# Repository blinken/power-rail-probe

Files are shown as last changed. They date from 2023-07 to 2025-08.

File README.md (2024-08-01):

# Power rail probe

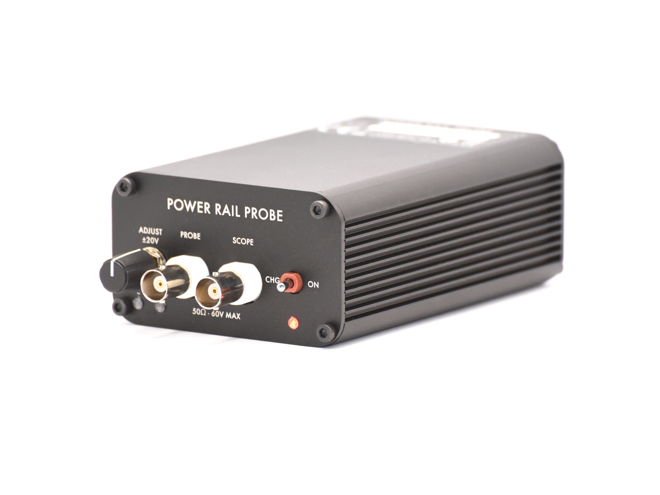
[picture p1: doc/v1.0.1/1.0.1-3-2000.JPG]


**An Open Hardware low-noise power rail oscilloscope probe**, loosely based on the excellent writeup by
[Andrew Levido](https://circuitcellar.com/research-design-hub/projects/building-a-power-rail-probe/)
[[PDF archive](doc/circuit_cellar-building_a_power_rail_probe.pdf)].

The probe allows you to measure millivolt-level ripple on a power rail up to 20V,
using a normal oscilloscope, by applying a vertical offset. This open design costs <10% of the price of the [Tektronix TPR1000](https://www.tek.com/en/datasheet/active-power-rail-probes).

Here's how it works:

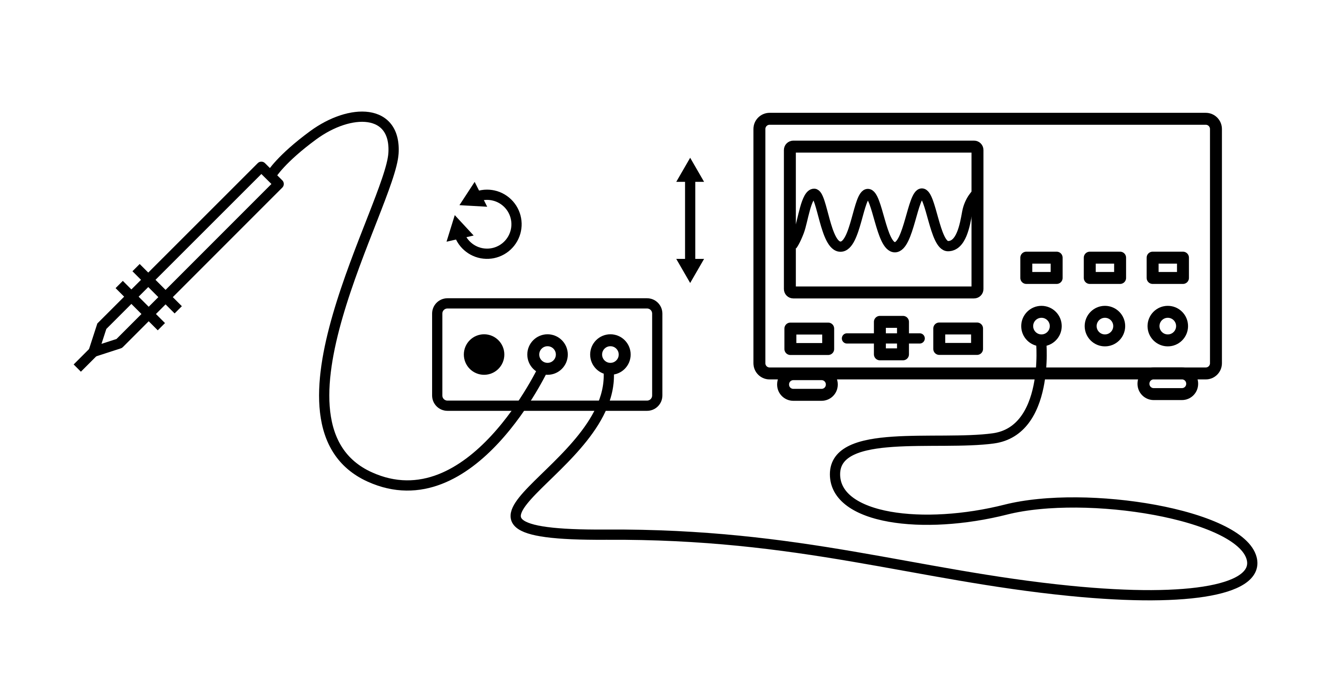
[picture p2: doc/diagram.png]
Connection diagram


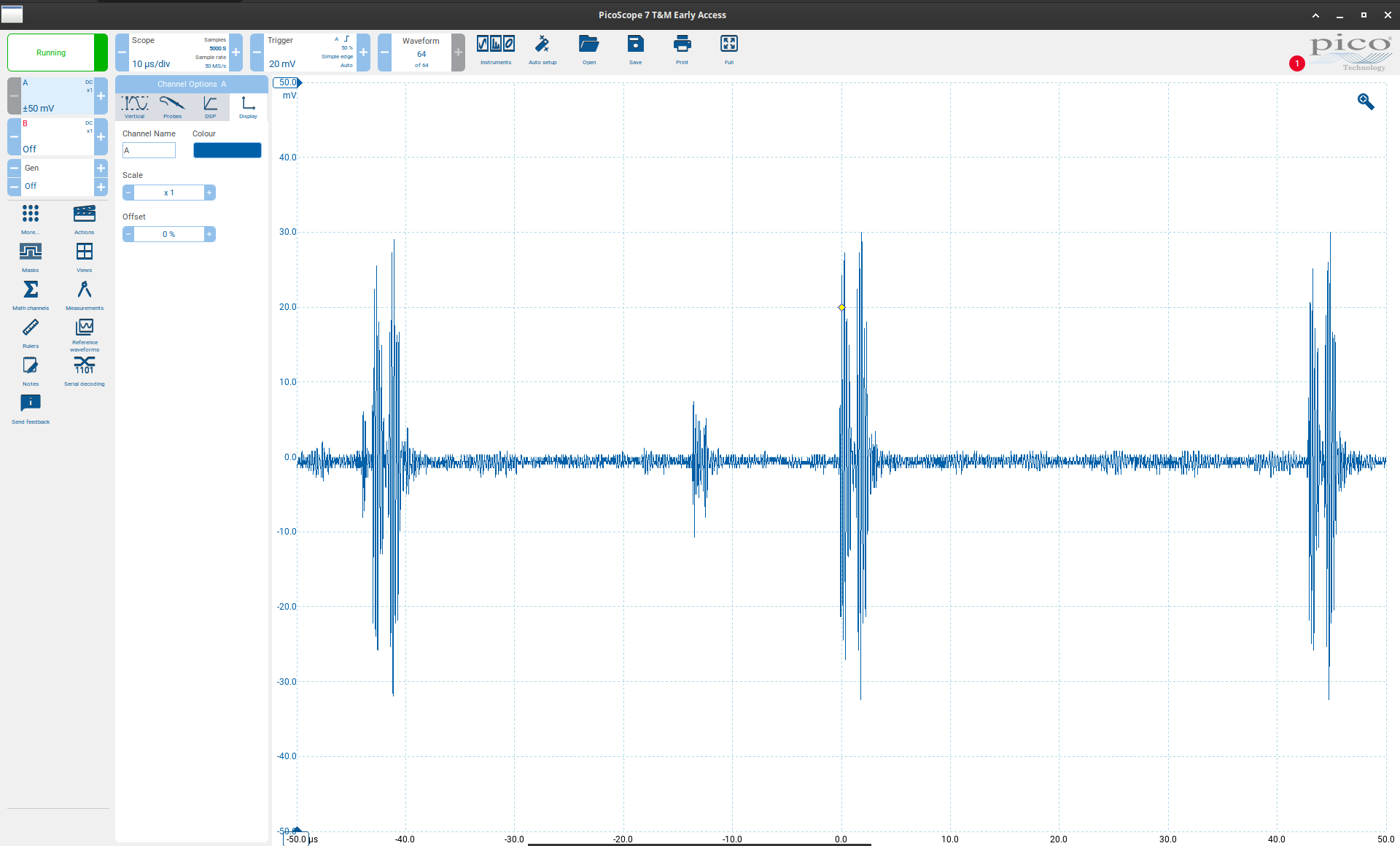
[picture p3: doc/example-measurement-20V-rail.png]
Example measurement showing ~50mV ripple on a 20V rail


*Measurement of 60mV p-p ripple on a 20V rail (ie. ripple 19.97V - 20.03V) using an inexpensive [Picoscope 2204A](https://www.picotech.com/oscilloscope/2000/picoscope-2000-specifications)*

The probe is directly connected to a power rail you're interested in (eg, via a
1X oscilloscope probe, or a direct cable connection).  AC is passed, and an
adjustable offset is applied to the DC voltage. The offset is fixed, allowing
DC sag and drift to be examined.

Your oscilloscope sees 0V DC, allowing power supply ripple and transients to be
viewed at the 1 mV/div setting, rather than 5 V/div. It's effectively a much
more powerful DC offset function for your oscilloscope.

## Specifications

### v1.0.1

 * Max voltage offset ±20V
 * Input impedance 50kΩ (0 - 30kHz) / 50Ω (30kHz - 1GHz)
 * Average signal attenuation of 1:1.2 (-0.9 dB +/- 1dB)
 * Frequency response (S12) flat within 1dB through 490MHz
 * Noise <500 µV<sub>p-p</sub> over full bandwidth
 * Active signal range ±1V
 * Indication of over-range signal (above or below offset setting)
 * High-precision Nidec M-1305 5-turn potentiometer for accurate offset adjustment
 * Isolation between chassis/USB and BNC test connectors
 * Battery powered to minimise noise
 * Li-Ion 18650 batteries rechargeable via USB-C connector (9V+ USB-PD supply required) or via DC barrel jack

The probe should be connected to an oscilloscope set to 50-ohm input impedance, and
works best with inputs <1-ohm impedance.

[Feedback and comments on the design](https://github.com/blinken/power-rail-probe/issues) are very much appreciated.

## How to buy

Version 1.0 is available [to purchase fully assembled here](https://paradar.co.uk/products/low-noise-oscilloscope-power-rail-probe)
for approx. £249 (USD $317, EUR €287). Purchasing a fully assembled unit helps to fund development!

If you would like to assemble the v1.0 probe yourself, blank PCBs, enclosures
and machined front panels are also available at [paradar.co.uk](https://paradar.co.uk/products/low-noise-oscilloscope-power-rail-probe).

Gerber files and a full BOM & schematic are available below under a CC BY-SA 4.0 license.

## Versions

The project is under active development, and there are several versions:

| Version | Status | Description | Performance |
| --- | --- | --- | --- |
| [v1.0](https://github.com/blinken/power-rail-probe/tree/v1.0) | Completed | Initial proof-of-concept | Functions well. Frequency response flat within 1.3dB to 500MHz. Similar (or slightly better) noise levels vs v1.1 |
| v1.0.1 | Complete, characterised and [available](https://paradar.co.uk/products/low-noise-oscilloscope-power-rail-probe) | Fix bugs from 1.0 and improve manufacturability | Improved frequency response vs v1.0, plus indicators for over/under range |
| v1.1 | Simulation complete | Includes additional compensation & lessons learned from v1.0 | Untested. Frequency response estimated from simulation as flat to within 0.5dB to 1GHz |

## Schematic

### v1.0

[[PDF](doc/schematic.pdf)] [[KiCanvas](https://kicanvas.org/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)]

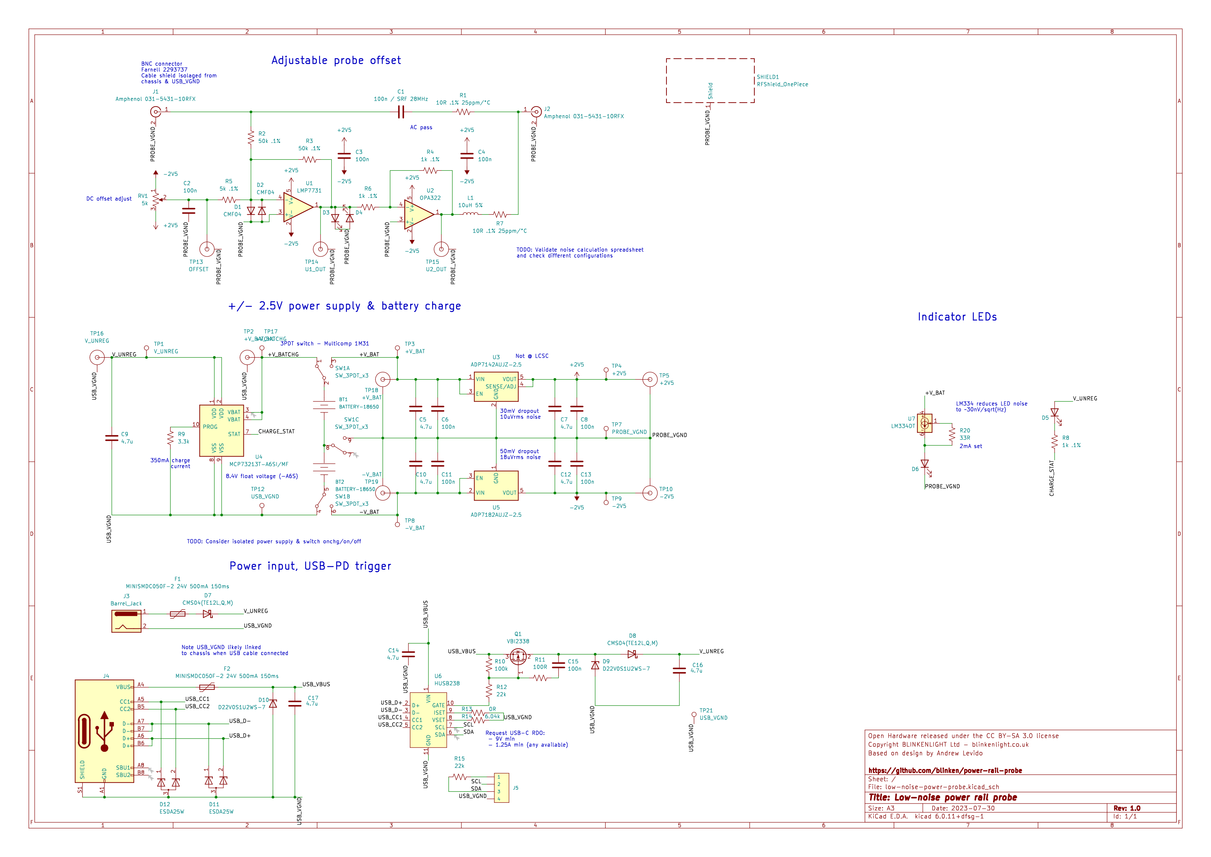
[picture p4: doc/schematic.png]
Power rail probe, schematic


### v1.0.1

[[KiCanvas](https://kicanvas.org/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)]

## Layout

### v1.0

[[PDF](doc/layout.pdf)] [[KiCanvas](https://kicanvas.org/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)]

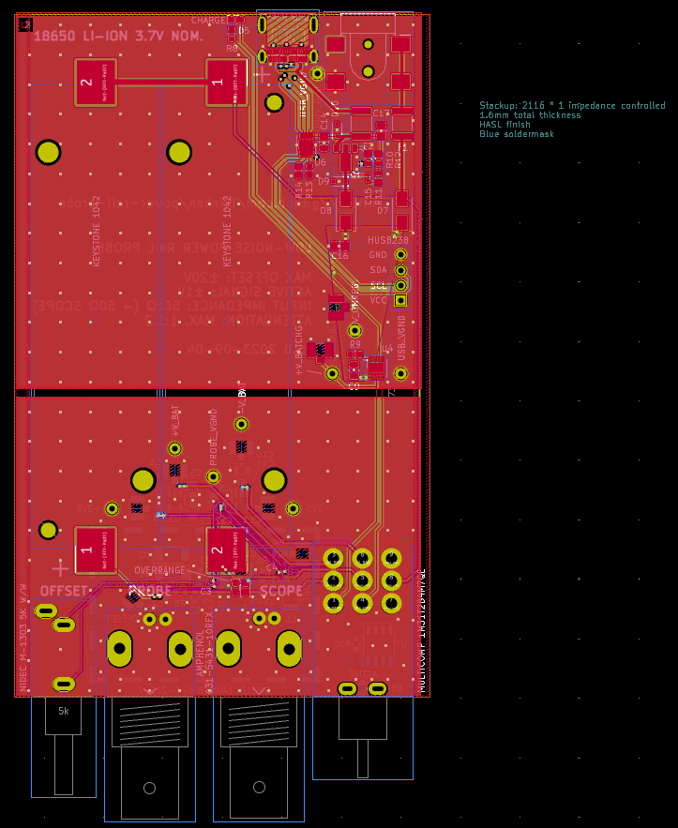
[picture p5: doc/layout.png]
Power rail probe, PCB layout


### v1.0.1

This version is under active development.

[[KiCanvas](https://kicanvas.org/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)]

## Frequency response

### v1.0.1

The probe's frequency response is flat within 1dB between approximately 3MHz and 490MHz, and flat within 2.5dB between approximately 150kHz and 550Mhz.

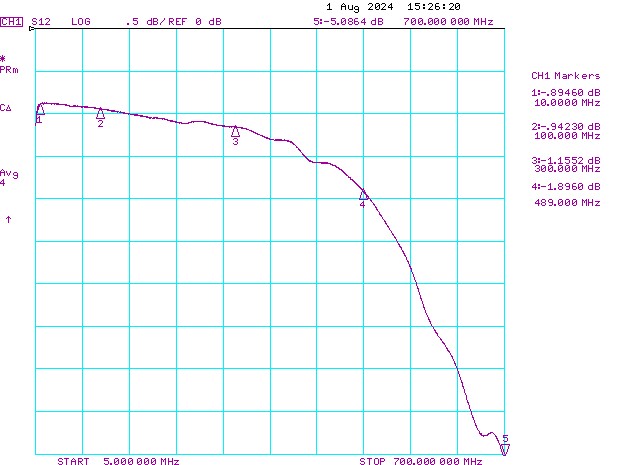
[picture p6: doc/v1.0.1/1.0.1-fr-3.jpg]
Chart of frequency response from 5MHz to 700MHz


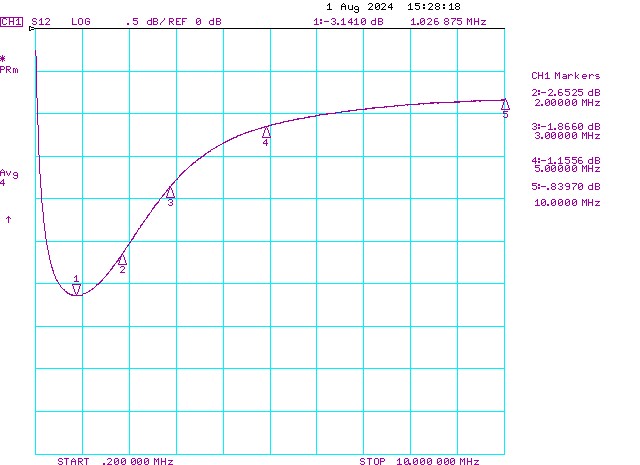
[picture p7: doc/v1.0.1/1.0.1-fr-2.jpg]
Chart of frequency response from 200kHz to 10MHz


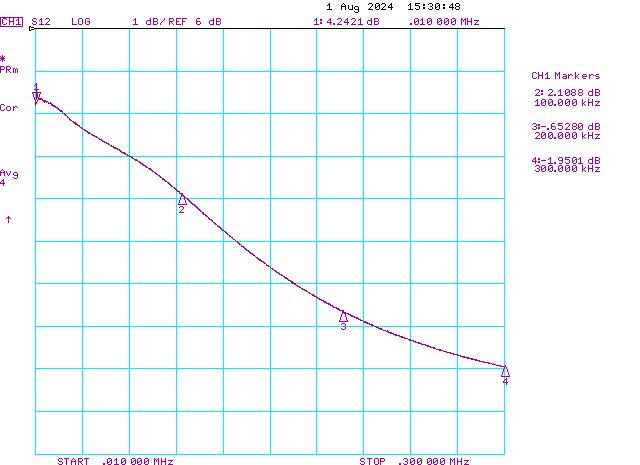
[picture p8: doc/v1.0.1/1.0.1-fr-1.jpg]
Chart of frequency response from 10kHz to 300kHz


### v1.0

Performance is flat within 1.3dB to 500MHz, aside from a 3.7dB dip at approx 1.2MHz.

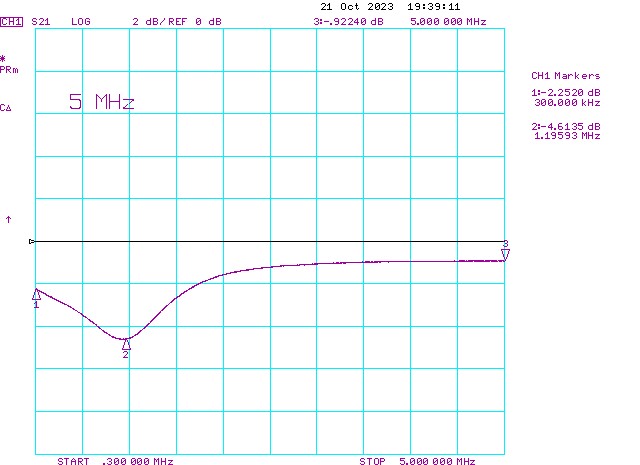
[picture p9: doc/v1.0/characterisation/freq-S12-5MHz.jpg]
Chart of frequency response from 300kHz to 5MHz


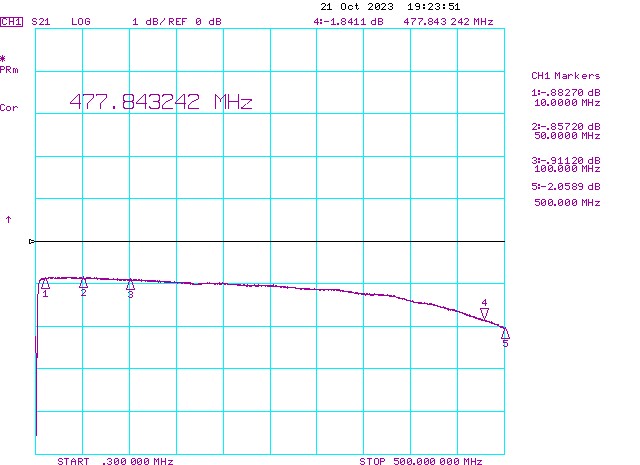
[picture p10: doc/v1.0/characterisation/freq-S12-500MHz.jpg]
Chart of frequency response from 300kHz to 500MHz


### v1.1

This version has not yet been manufactured, and the results below are from simulation in SPICE.

Frequency response is flat within 0.5dB to 1GHz, with the exception of a 2.5dB peak at 71.8kHz.

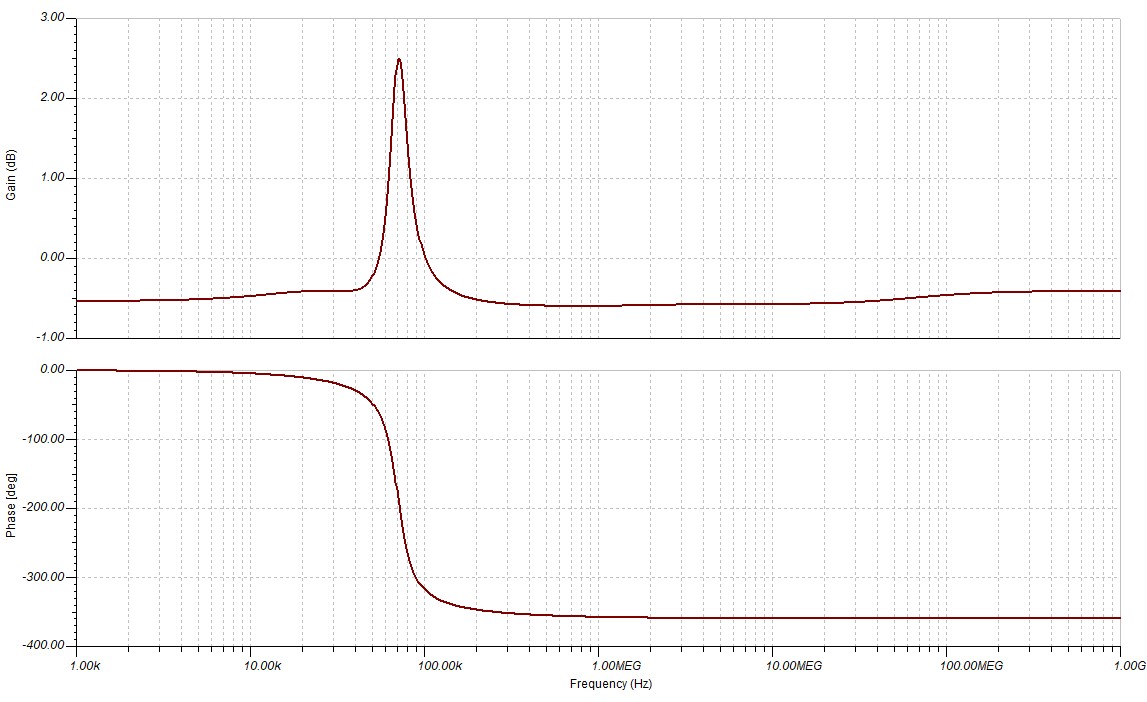
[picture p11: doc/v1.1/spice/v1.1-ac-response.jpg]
Chart frequency response 10Hz and 1GHz


The chart above was obtained through simulation with TINA-TI SPICE, assuming an
input impedance of 0.1Ω. Measuring the frequency response with a 50Ω source
(ie. a standard VNA) will produce different results.

[[Simulation files](./doc/v1.1/spice)]

## Noise analysis

The design aims to minimise the noise introduced by the instrument. Low-noise
operation is achieved with battery operation, and by avoiding semiconductors in
the critical path.  Batteries are recharged when the instrument is turned off.

### v1.0 & v1.1

The total noise introduced by the probe ([simulated in TINA-TI SPICE v9](./doc/v1.1/spice)) is
78.7 µVrms when measuring over the total instrument bandwidth 10Hz and 1GHz.

The noise introduced depends on the bandwidth of the measurement. Reducing the
measured bandwidth will reduce the noise introduced, and so the numbers below
are a worst-case upper limit. For example, a measurement between 10kHz and
20kHz, the probe will introduce 12.9 µVrms noise (-84.8 dBm).

| Measurement bandwidth  | Total RMS noise | Total peak-to-peak noise (6σ) | Power (Z<sub>0</sub>=50Ω) |
| --- | --- | --- | --- |
| 10Hz - 10kHz | 12.9 µV<sub>rms</sub> | 77.4 µV<sub>p-p</sub> | -84.8 dBm |
| 1kHz - 10kHz | 11.9 µV<sub>rms</sub> | 71.4 µV<sub>p-p</sub> | -85.5 dBm |
| 10Hz - 100kHz | 76.3 µV<sub>rms</sub> | 457.8 µV<sub>p-p</sub> | -69.3 dBm |
| 10Hz - 1MHz | 78.4 µV<sub>rms</sub> | 470.4 µV<sub>p-p</sub> | -69.1 dBm |
| 10Hz - 10MHz | 78.5 µV<sub>rms</sub> | 471.0 µV<sub>p-p</sub> | -69.1 dBm |
| 10Hz - 100MHz | 78.5 µV<sub>rms</sub> | 471.0 µV<sub>p-p</sub> | -69.1 dBm |
| 10Hz - 1GHz | 78.7 µV<sub>rms</sub> | 472.2 µV<sub>p-p</sub> | -69.1 dBm |

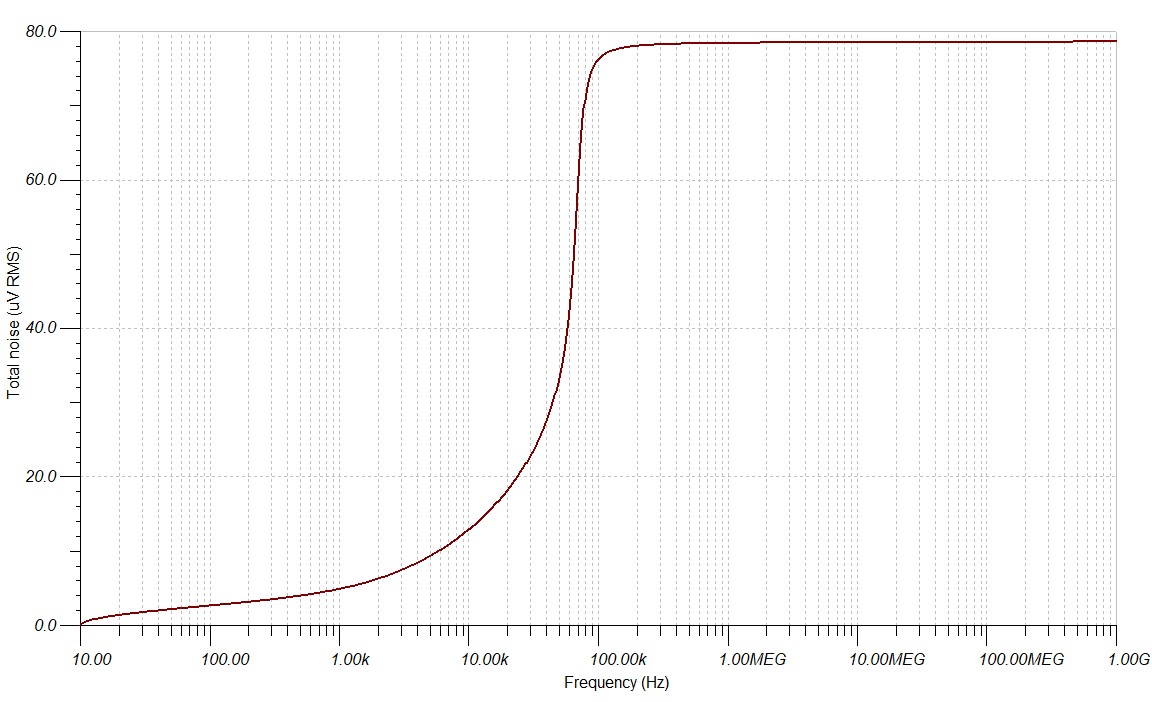
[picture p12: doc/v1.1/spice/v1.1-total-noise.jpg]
Chart of total noise between 10Hz and 1GHz


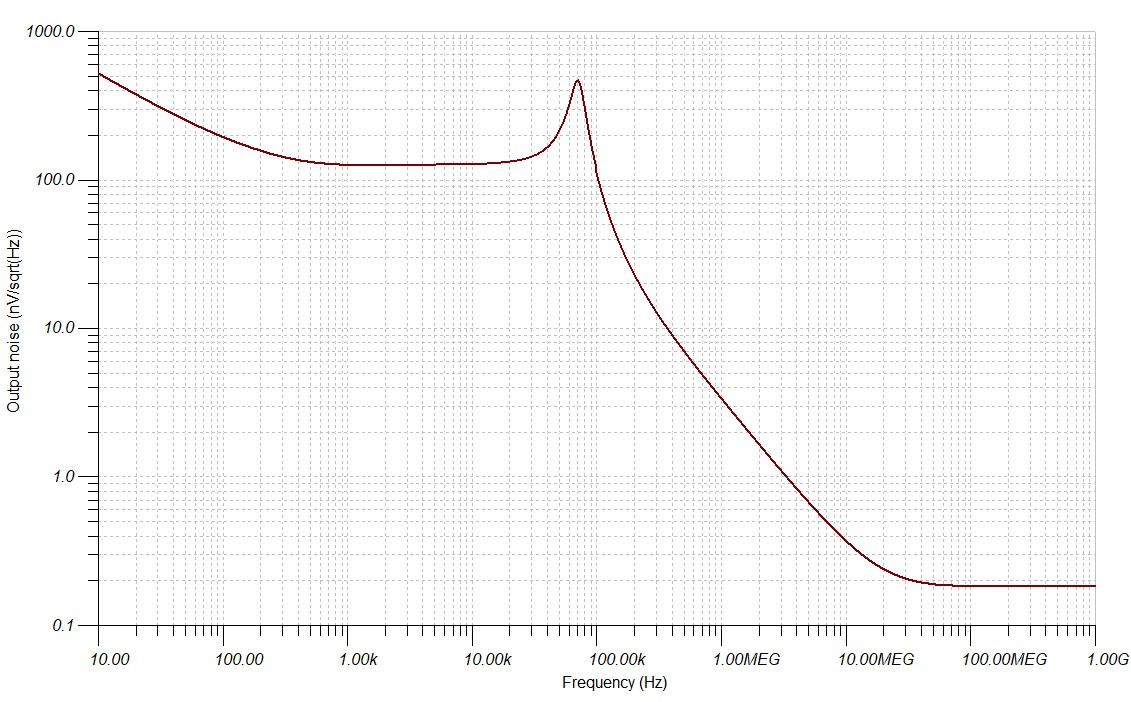
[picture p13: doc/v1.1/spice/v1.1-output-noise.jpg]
Chart of output noise between 10Hz and 1GHz


## Bill of materials

### v1.0

[[CSV](./bom/low-noise-power-probe-bom-pcba.csv)]

 * [LMP7731](https://www.ti.com/lit/ds/symlink/lmp7731.pdf) Ultra-low noise precision RRIO opamp
 * [OPA322](https://www.ti.com/lit/ds/symlink/opa322.pdf) 20-MHz low-noise 1.8-V RRIO opamp
 * [ADP7142AUJZ-2.5](https://www.analog.com/media/en/technical-documentation/data-sheets/ADP7142.pdf) +2.5V 200 mA low noise LDO Linear Regulator
 * [ADP7182AUJZ-2.5](https://www.analog.com/media/en/technical-documentation/data-sheets/ADP7182.pdf) -2.5V 200 mA low noise LDO Linear Regulator
 * [MCP73213T-A6SI/MF](https://ww1.microchip.com/downloads/aemDocuments/documents/OTH/ProductDocuments/DataSheets/20002190D.pdf) Dual-cell, Li-Ion/Li-Polymer charge management controller, 8.4V float
 * [HUSB238](https://en.hynetek.com/uploadfiles/site/219/news/1ad9e8fa-b39c-46a5-a984-152771d4ac69.pdf) Standalone USB PD sink controller
 * 2x [Amphenol 031-5431-10RFX](https://www.farnell.com/cad/2353820.pdf) isolated BNC connectors
 * [Multicomp 1M31T2B4M7QE](https://www.farnell.com/datasheets/1810474.pdf) 3PDT switch
 * [Molex 105450-0101](https://www.molex.com/en-us/products/part-detail/1054500101) USB-C receptacle
 * [Nidec M-1303](https://www.mouser.co.uk/datasheet/2/972/m-1827099.pdf) 5k 3-turn potentiometer
 * [DC050-T](https://datasheet.lcsc.com/lcsc/1912111437_SHOU-HAN-DC050-T_C431534.pdf) barrel jack connector
 * Selection of SMD resistors, capacitors, LEDs and diodes as marked
 * An aluminium extrusion case suitable for a 70x114mm board - eg, [AliExpress](https://www.aliexpress.com/item/1005003326971939.html)

A blank PCB, aluminium extrusion case and machined front/rear panels can be purchased as a kit from [paradar.co.uk](https://paradar.co.uk/products/low-noise-oscilloscope-power-rail-probe?variant=43212423233713).

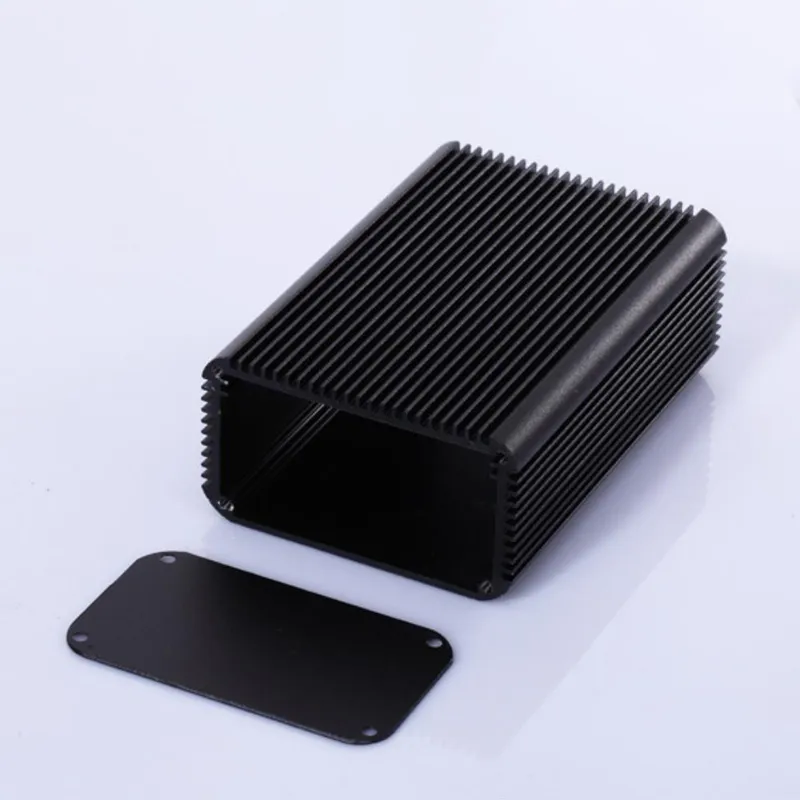
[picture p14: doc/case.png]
Aluminium enclosure 70x115mm internal size

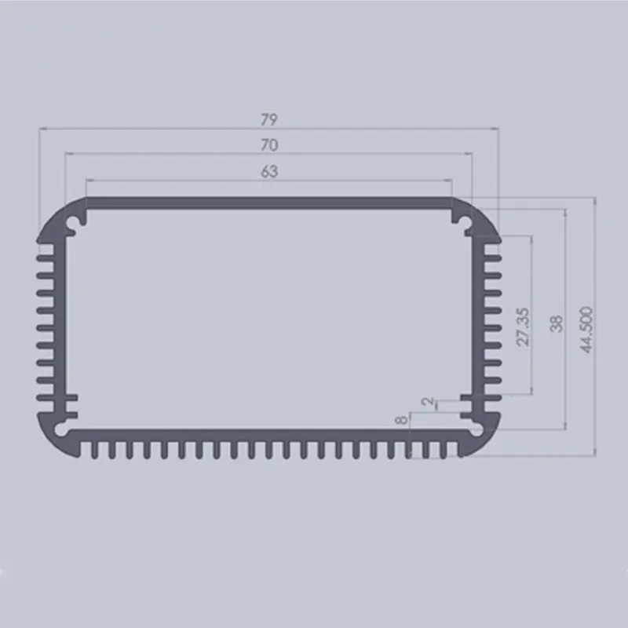
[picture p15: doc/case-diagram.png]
Aluminium enclosure, diagram with dimensions


## Front/rear panel layout

### v1.0

Click to expand.

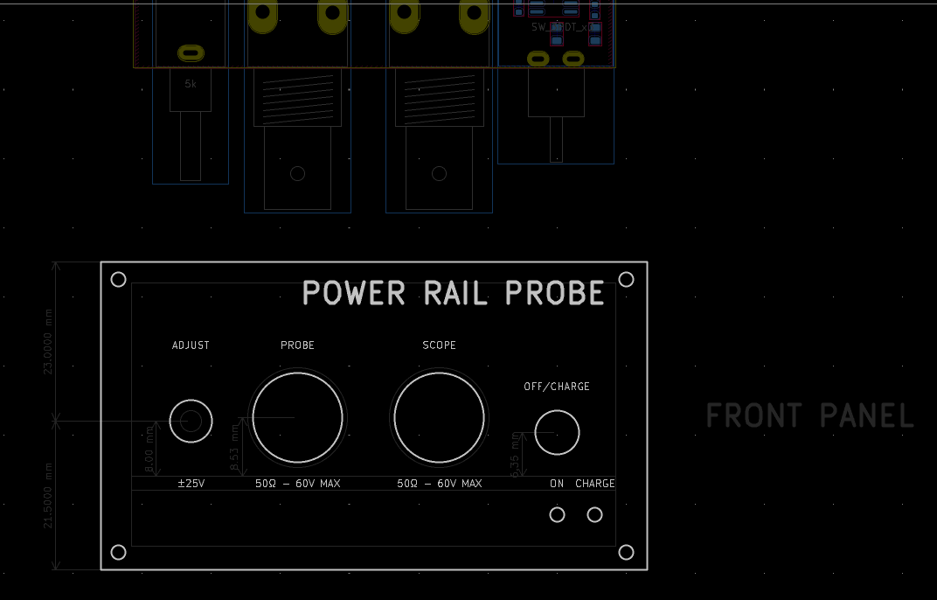
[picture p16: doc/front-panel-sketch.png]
Power rail probe, front panel layout diagram

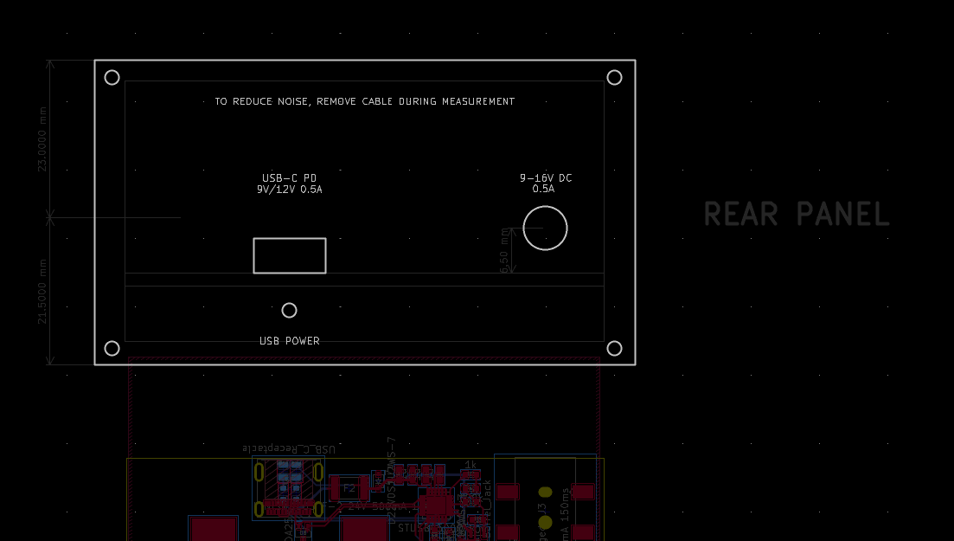
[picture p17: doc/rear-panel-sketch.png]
Power rail probe, rear panel layout diagram


## License

[CC BY-SA 4.0](https://creativecommons.org/licenses/by-sa/4.0/)

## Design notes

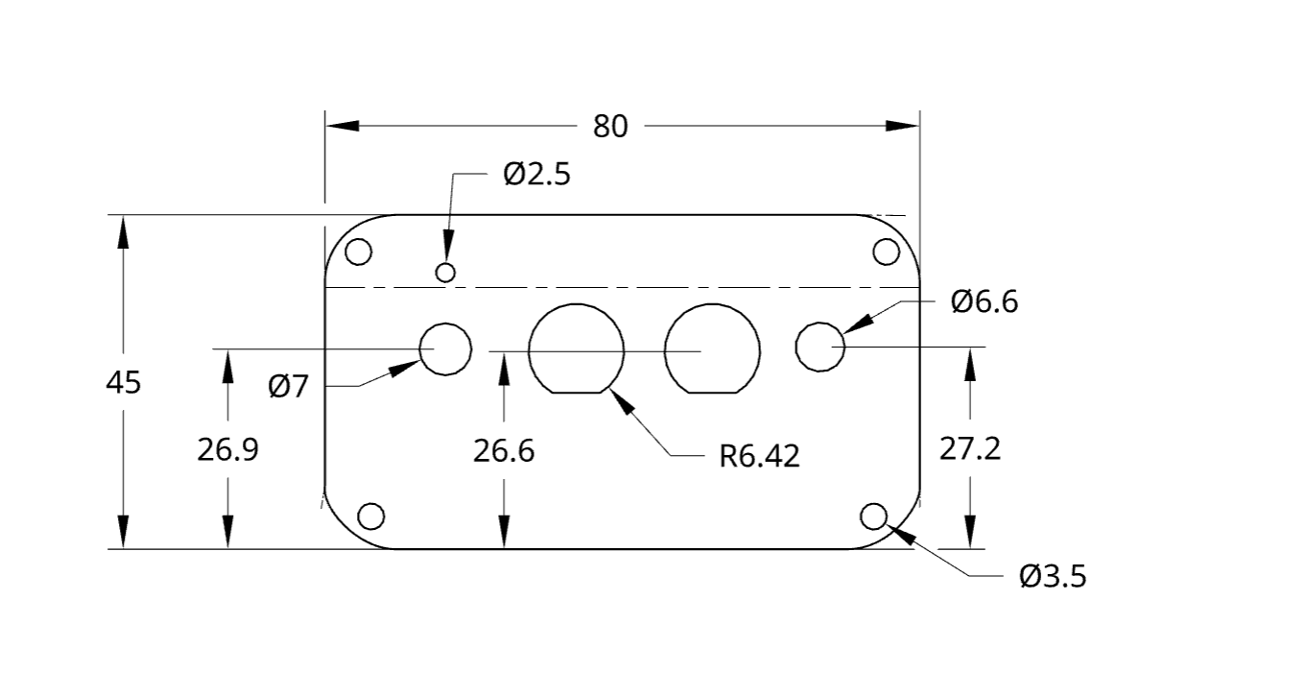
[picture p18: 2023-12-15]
doc/front-panel-drawing.png

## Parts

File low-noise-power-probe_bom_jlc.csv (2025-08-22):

Comment | Designator | Footprint | LCSC Part Number
Dual_Battery_Cell | BT1 | Battery-holder-18650-MYOUNG-BH-18650-A1BJ021 | C20606804
100n / SRF 28MHz | C1 | C_0402_1005Metric | C77020
100n | C2,C15,C16,C17,C18,C20,C23 | C_0402_1005Metric | C77020
2.2u | C4,C6,C8,C11,C13,C21,C22,C24,C25 | C_0402_1005Metric | C2999759
4.7u | C5,C7,C9,C10,C12,C14 | C_0805_2012Metric | C162420
Red 1.8V | D1,D3,D4,D5,D6 | LED_0603_1608Metric_polaritysilk | C965799
3V3 | D2 | D_SOD-123 | C19077392
1N5819WS | D7,D8 | D_SOD-323 | C191023
SD24-MS | D9,D10,D11,D12,D13,D14,D15 | D_SOD-323_silkpolarity | C2982180
SMD1206-050C-24V | F1,F2,F3,F4 | Fuse_1206_3216Metric | C2843983
Amphenol 901-10138 | J1,J2 | SMA_Amphenol_901-10138_Horizontal | C5541227
DC-005 2.0 | J3 | BarrelJack_Horizontal | C16214
USB_C_Receptacle | J4 | USB_C_Receptacle_Molex_105450-0101 | C134092
RF Shield Clip | J8,J9,J11,J12 | ICSRC6508-015SFR | C238200
10uH 5% | L1 | L_1812_4532Metric | C3223474
WSE3099 | Q1 | SOT-89-3 | C148359
HL2312 | Q2,Q3 | SOT-23 | C28646272
10R 1% 200ppm/°C | R1,R7 | R_0603_1608Metric | C2791798
50k .1% | R2,R3 | R_0603_1608Metric | C304067
1k .1% | R4,R6 | R_0603_1608Metric | C2989112
3.3k | R5 | R_0603_1608Metric | C22978
1k | R8,R21,R23,R31 | R_0603_1608Metric | C2989112
5k | R9 | R_0603_1608Metric | C2828621
50k | R10,R22,R24,R30 | R_0603_1608Metric | C304067
100R | R11,R29,R32,R33 | R_0603_1608Metric | C22775
6.04k | R12,R14 | R_0603_1608Metric | C25977
0R | R13,R26 | R_0603_1608Metric | C21189
10M | R15 | R_0603_1608Metric | C7250
620 | R16,R17 | R_0603_1608Metric | C203710
33R | R20 | R_0603_1608Metric | C966651
150R | R27 | R_0603_1608Metric | C22808
270R | R28 | R_0603_1608Metric | C22966
OPA322 | U1,U2 | SOT-23-5 | C2057629
ADP7142AUJZ-2.5 | U3 | TSOT-23-5 | C9900054564
MCP73213T-A6SI/MF | U4 | DFN-10-1EP_3x3mm_P0.5mm_EP1.55x2.48mm | C481367
ADP7182AUJZ-2.5 | U5 | TSOT-23-5 | C462196
HUSB238 | U6 | DFN-10-1EP_3x3mm_P0.5mm_EP1.65x2.38mm | C7471904
LM334DT | U7 | SO-8_3.9x4.9mm_P1.27mm | C140388
LM311DR | U8 | SOIC-8_3.9x4.9mm_P1.27mm | C12597
~ | U9 | VSON-8-1EP_3x3mm_P0.65mm_EP1.65x2.4mm | C2865505

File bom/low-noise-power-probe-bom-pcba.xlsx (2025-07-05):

Item | Qty | Reference(s) | Value | Footprint | Datasheet | LCSC | Manufacturer | Part | Substitution permitted?
4 | 9 | C1, C2, C3, C4, C6, C8, C11, C13, C15 | 100n | Capacitor_SMD:C_0402_1005Metric | ~ | C77020 | Murata | GRM155R71H104KE14D | No
5 | 8 | C5, C7, C9, C10, C12, C14, C16, C17 | 4.7u | Capacitor_SMD:C_0805_2012Metric | ~ | C162420 | Murata | GRM21BR61H475KE51L | No
6 | 2 | D1, D2 | CMF04 | Diode_SMD:D_SOD-128 | https://www.mouser.co.uk/datasheet/2/408/CMF04_datasheet_en_20180615-1150848.pdf | C150146 | TOSHIBA | CMF04(TE12L,Q,M) | No
7 | 4 | D3, D4, D5, D6 | Red 1.8V | LED_SMD:LED_0603_1608Metric | https://datasheet.lcsc.com/lcsc/1810181516_Vishay-Intertech-TLMS1000-GS08_C241893.pdf | C241893 | Vishay Intertech | TLMS1000-GS08 | Yes
8 | 2 | D7, D8 | CMS04(TE12L,Q,M) | Diode_SMD:D_SMA | https://datasheet.lcsc.com/lcsc/2008241604_TOSHIBA-CMS04-TE12L-Q-M_C603062.pdf | C603062 | TOSHIBA | CMS04(TE12L,Q,M) | No
9 | 2 | D9, D10 | D22V0S1U2WS-7 | Diode_SMD:D_SOD-323 | https://datasheet.lcsc.com/lcsc/2201101700_Diodes-Incorporated-D22V0S1U2WS-7_C1974624.pdf | C1974624 | Diodes Incorporated | D22V0S1U2WS-7 | Yes
10 | 2 | D11, D12 | ESDA25W | Package_TO_SOT_SMD:SOT-323_SC-70 | https://datasheet.lcsc.com/lcsc/2201201600_STMicroelectronics-ESDA25W_C2935152.pdf | C2935152 | STMicroelectronics | ESDA25W | Yes
11 | 2 | F1, F2 | MINISMDC050F-2 24V 500mA 150ms | Fuse:Fuse_1812_4532Metric | https://datasheet.lcsc.com/lcsc/2108070630_Littelfuse-MINISMDC050F-2_C2649901.pdf | C2649901 | Littelfuse | MINISMDC050F-2 | Yes
13 | 1 | J3 | Barrel_Jack | misc:BarrelJack_Shou_Han_DC050-T_SMT_Horizontal | https://datasheet.lcsc.com/lcsc/1912111437_SHOU-HAN-DC050-T_C431534.pdf | C431534 | Shou Han | DC050-T | Yes
14 | 1 | J4 | USB_C_Receptacle | Connector_USB:USB_C_Receptacle_Molex_105450-0101 | https://datasheet.lcsc.com/lcsc/1811131824_MOLEX-1054500101_C134092.pdf | C134092 | Molex | 1054500101 | Yes
15 | 1 | L1 | 10uH 5% | Inductor_SMD:L_1210_3225Metric | ~ | C2045047 | Murata | LQH32NH100J23L | No
16 | 1 | Q1 | VBI2338 | Package_TO_SOT_SMD:SOT-89-3 | https://datasheet.lcsc.com/lcsc/2308161358_VBsemi-Elec-VBI2338_C416321.pdf | C416321 | VBsemi Elec | VBI2338 | Yes
17 | 2 | R1, R7 | 10R .1% 25ppm/°C | Resistor_SMD:R_0402_1005Metric | ~ | C705629 | Yageo | RT0402BRD0710RL | Yes
18 | 2 | R2, R3 | 50k .1% | Resistor_SMD:R_0603_1608Metric | ~ | C861451 | Yageo | RT0603BRD0750KL | Yes
19 | 3 | R4, R6, R8 | 1k .1% | Resistor_SMD:R_0603_1608Metric | ~ | C110776 | Yageo | RT0603BRD071KL | Yes
20 | 1 | R5 | 5k .1% | Resistor_SMD:R_0603_1608Metric | ~ | C862232 | Yageo | RT0603BRE075KL | Yes
21 | 1 | R9 | 3.3k | Resistor_SMD:R_0603_1608Metric | ~ | C108078 | Yageo | RC0603FR-073K3L | Yes
22 | 1 | R10 | 100k | Resistor_SMD:R_0603_1608Metric | ~ | C14675 | Yageo | RC0603FR-07100KL | Yes
23 | 1 | R11 | 100R | Resistor_SMD:R_0603_1608Metric | ~ | C105588 | Yageo | RC0603FR-07100RL | Yes
24 | 2 | R12, R15 | 22k | Resistor_SMD:R_0603_1608Metric | ~ | C114065 | Yageo | RC0603FR-0722KL | Yes
25 | 1 | R13 | 0R | Resistor_SMD:R_0603_1608Metric | ~ | C192909 | Yageo | AF0603FR-070RL | Yes
26 | 1 | R14 | 6.04k | Resistor_SMD:R_0603_1608Metric | ~ | C141680 | Yageo | RC0603FR-076K04L | Yes
27 | 1 | R20 | 33R | Resistor_SMD:R_0603_1608Metric | ~ | C108661 | Yageo | RC0603FR-0733RL | Yes
31 | 1 | TP5 | +2V5 | rf-connectors:U.FL-Hirose |  | C88374 | Hirose | U.FL-R-SMT-1(80) | Yes
32 | 1 | TP10 | -2V5 | rf-connectors:U.FL-Hirose |  | C88374 | Hirose | U.FL-R-SMT-1(80) | Yes
33 | 1 | TP13 | OFFSET | rf-connectors:U.FL-Hirose |  | C88374 | Hirose | U.FL-R-SMT-1(80) | Yes
34 | 1 | TP14 | U1_OUT | rf-connectors:U.FL-Hirose |  | C88374 | Hirose | U.FL-R-SMT-1(80) | Yes
35 | 1 | TP15 | U2_OUT | rf-connectors:U.FL-Hirose |  | C88374 | Hirose | U.FL-R-SMT-1(80) | Yes
36 | 1 | TP16 | V_UNREG | rf-connectors:U.FL-Hirose |  | C88374 | Hirose | U.FL-R-SMT-1(80) | Yes
37 | 1 | TP17 | +V_BATCHG | rf-connectors:U.FL-Hirose |  | C88374 | Hirose | U.FL-R-SMT-1(80) | Yes
38 | 1 | TP18 | +V_BAT | rf-connectors:U.FL-Hirose |  | C88374 | Hirose | U.FL-R-SMT-1(80) | Yes
39 | 1 | TP19 | -V_BAT | rf-connectors:U.FL-Hirose |  | C88374 | Hirose | U.FL-R-SMT-1(80) | Yes
40 | 1 | U1 | LMP7731 | Package_TO_SOT_SMD:SOT-23-5 | https://www.ti.com/lit/ds/symlink/lmp7731.pdf | C202252 | Texas Instruments | LMP7731MF | No
41 | 1 | U2 | OPA322 | Package_TO_SOT_SMD:SOT-23-5 | https://www.ti.com/lit/ds/symlink/opa322.pdf | C2057408 | Texas Instruments | OPA322AIDBVT | No
42 | 1 | U3 | ADP7142AUJZ-2.5 | Package_TO_SOT_SMD:TSOT-23-5 | https://www.analog.com/media/en/technical-documentation/data-sheets/ADP7142.pdf |  | Texas Instruments | ADP7142AUJZ-2.5 | No
43 | 1 | U4 | MCP73213T-A6SI/MF | Package_DFN_QFN:DFN-10-1EP_3x3mm_P0.5mm_EP1.55x2.48mm | https://ww1.microchip.com/downloads/aemDocuments/documents/OTH/ProductDocuments/DataSheets/20002190D.pdf | C481367 | Microchip Tech | MCP73213T-A6SI/MF | No
44 | 1 | U5 | ADP7182AUJZ-2.5 | Package_TO_SOT_SMD:TSOT-23-5 | https://www.analog.com/media/en/technical-documentation/data-sheets/ADP7182.pdf | C462196 | Analog Devices | ADP7182AUJZ-2.5-R7 | No
45 | 1 | U6 | HUSB238 | Package_DFN_QFN:DFN-10-1EP_3x3mm_P0.5mm_EP1.65x2.38mm | https://en.hynetek.com/uploadfiles/site/219/news/1ad9e8fa-b39c-46a5-a984-152771d4ac69.pdf | C7471904 | Hynetek | HUSB238_002DD | No
46 | 1 | U7 | LM334DT | Package_SO:SO-8_3.9x4.9mm_P1.27mm | https://datasheet.lcsc.com/lcsc/2304140030_STMicroelectronics-LM334DT_C140388.pdf | C140388 | STMicroelectronics | LM334DT | No

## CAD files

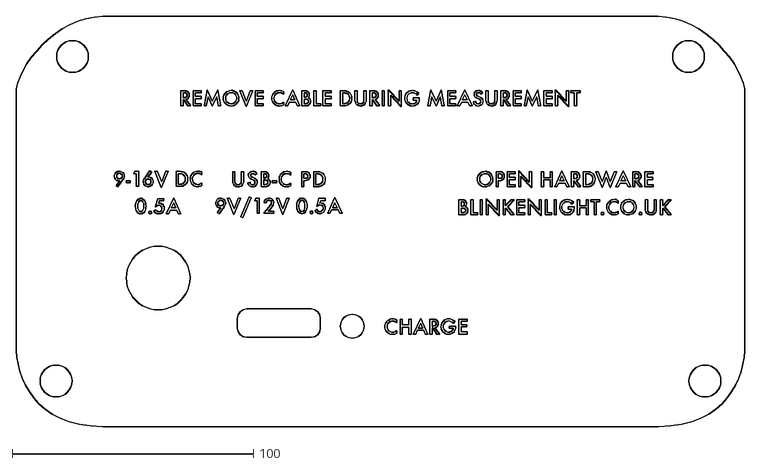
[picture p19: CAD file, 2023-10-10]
doc/rear-panel-marked-14.dxf
302.4 x 170.1

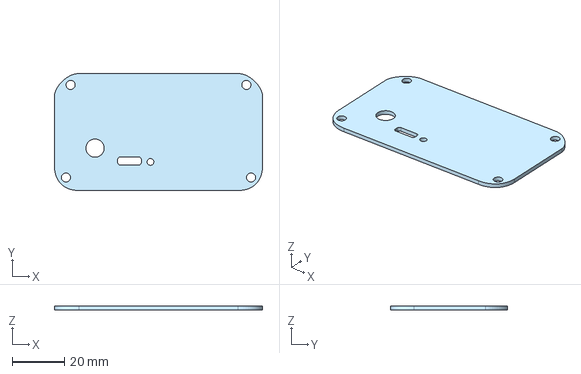
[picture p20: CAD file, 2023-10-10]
doc/rear-panel.step
80.0 x 45.0 x 1.50 mm

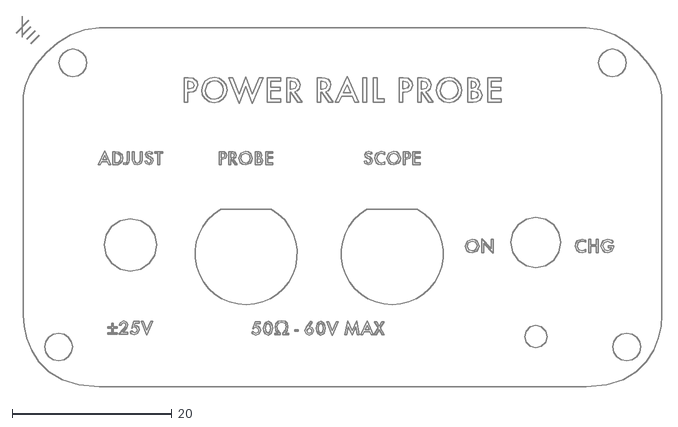
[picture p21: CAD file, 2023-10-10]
doc/front-panel-marked-14.dxf
80.9 x 46.5

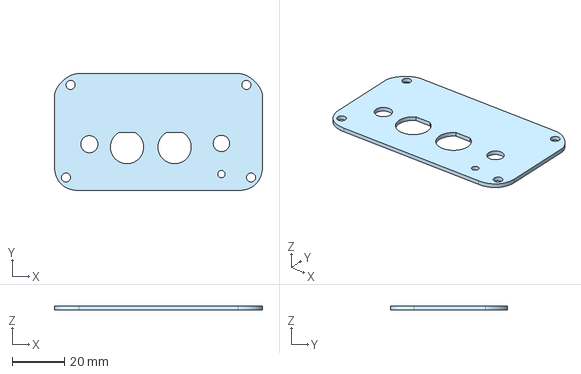
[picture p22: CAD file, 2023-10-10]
doc/front-panel.step
80.0 x 45.0 x 1.50 mm

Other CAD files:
doc/front-panel.3mf
doc/front-panel.dxf
doc/front-panel.stl
doc/rear-panel.3mf
doc/rear-panel.dxf
doc/rear-panel.stl

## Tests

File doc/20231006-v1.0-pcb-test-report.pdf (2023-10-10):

ITEM/项目 | DESCRIPTION/说明 | ACTUAL/结果
1 | Customer code/客户代码 | D0007
2 | Customer P/N/客户型号 | gb-low-noise-power-probe PCB
3 | Customer P/0/客户订单号 | PO20230907-1
4 | Shipment quantity/交货数量 | 10Pcs
5 | PCB type/PCB类型 | Rigid PCB
6 | Inspection standard/检查标准 | IPC-A-600H Class2
7 | UL plame class/UL number 耐燃与编 号 | 94V-0
8 | Laminate type/板材类型 | FR4 KB6167F TG≧170
9 | Surface Finish/表面处理 | HAL(LEAD-FREE)
10 | Date code /生产周期 | 3723
11 | Ship date / 出货日期 | 2023/9/19
12 | Production area/生产地 | China
13 | Meet with RoHS/符合RoHS | Yes
14 | Customer DWG/客户图纸 | Yes

Angel

Vic OuYang

Date : | 2023/9/19 | Signature

All PCBs are manufactured in comply with original Gerber and Specifications of customer requirement, After 100% inspection,the raw materials, fabrications,testing,appearance and functions of PCB are all conforming to customer SPEC and IPC standards,All data listed on this report hereby-certifition are truly to meet customer's request.

Thanks for your attention !!

Certified by : | Quality Assurance Manager

## CERTIFICATION OF COMPLIANCE

## Dear Customer:

尊敬的客户：

兹证明我们生产的印制电路板符合RoHS 欧盟指令 2011/65 及其修订指令2015/863 法规规定。

序号 NO. | 测试项目 Test Item | 限量 % Limit | 结果 Result
1 | 铅 Lead (pb) | 0.1(1000ppm) | Not detected
2 | 镉 Cadmium(Cd) | 0.01(100ppm) | Not detected
3 | 汞 Mercury(Hg). | 0.1(1000ppm) | Not detected
4 | 六价铬 Chromium VI(Cr+6 or CrVI) | 0.1(1000ppm) | Not detected
5 | 多溴联苯 PBBs | 0.1(1000ppm) | Not detected
6 | 多溴二苯醚 PBDEs | 0.1(1000ppm) | Not detected
7 | 邻苯二甲酸二异丁酯 DIBP | 0.1(1000ppm) | Not detected
8 | 邻苯二甲酸（2-乙基己基酯） DEHP | 0.1(1000ppm) | Not detected
9 | 邻苯二甲酸丁苄酯 BBP | 0.1(1000ppm) | Not detected
10 | 邻苯二甲酸二丁酯DBP | 0.1(1000ppm) | Not detected
Date/日期： | 2023/9/19 | Date/日期： | 2023/9/19
Prepared by/制作人： | Jenny | Approved by/审核人： | Lee

## RoHS Certificate of Compliance

### RoHS 符合性证明

Dear Customer,

This document declare that the above part number comply with the RoHS Directive 2002/95/EC, RoHS2 directive 2011/65/EU and RoHS3 directive 2015/863

Customer/客户代码： | D0007 | Customer Part No. 客户型号: | gb-low-noise-power-probe PCB

Item项目 | Description / 描述 | Specification / 规格 | Actual / 实际 | Acc/Rej
1.0 Visual Appearance/ 外观检查
2.0 Material 材料 | PCB Type /板类型 | Rigid PCB | Rigid PCB | ACC
| Material Type/ 基材类型 | FR4 KB6167F TG≧170 | FR4 KB6167F TG≧170 | ACC
| Finished Board Thk(mm)/完成板厚 | 1.6(+0.16/-0.16) | 1.58 | ACC
| Flammability Class : 防火等级 | 94V-0 | 94V-0 | ACC
3.0 Plating Thickness 镀层厚度 | Hole Wall Cu THK (Min) / 最小孔壁铜厚 | 20um | 25.3um | ACC
| Surface Cu THK / 完成铜厚 | 1OZ | 44.4um | ACC
| Plated Nickel (Min)/ 镀镍 | / | / | /
| Plated gold (Min)/ 镀金 | / | / | /
| Plated Tin/Lead /镀锡 | / | / | /
4.0 Line Inspection 导线检查 | Line Width (mm) / 线宽 | 0.183(+/-20%) | 0.190 | ACC
| Line Spacing (mm) / 线距 | 0.145(+/-20%) | 0.160 | ACC
5.0 Solder Mask 阻 焊 / Legend 字符 /Peelable soldermask /可剥 离兰胶 | Solder Mask model / 阻焊型号 | KSM-S6189 | KSM-S6189 | ACC
| Solder Mask Color / 阻焊颜色 | 蓝色 Blue | 蓝色 Blue | ACC
| Legend Ink model / 字符类型 | M-211（W) | M-211（W) | ACC
| Legend Ink color / 字符颜色 | 白色 White | 白色 White | ACC
| Tape Test/3M / 胶带测试 | Not Peel off | Not Peel off | ACC
| Solvent test / 溶剂测试 | Not Peel off | Not Peel off | ACC
| Cover layer color / 覆盖膜颜色 | / | / | /
| Peelable soldermask /可剥离兰胶 | / | / | /
6.0 Mechanical Dimension / 外形 | Dimension size (mm) / 外形尺寸 | 124.78*79.78 | 124.73*79.79 | ACC
| V-Cut Thickness(mm) / V-cut余厚 | 0.4+/-0.10mm | 0.43 | ACC
| Angle(degree): / 角度 | 30+/-5˚ | 30 | ACC
| Bevelling(mm) / 斜边 | / | / | /
| Angle(degree) / 角度 | / | / | /
| Warp & Twist / 板翘曲 | ≤ 0.75% | 0.22% | ACC
7.0 Surface Finish/ 表面处理 | Surface Finish/表面处理 | HAL(LEAD-FREE) | HAL(LEAD-FREE) | ACC
| Request/要求 | Unit: um 1–40 | 19.64 | ACC
8.0 Function / Reliabilty test/ 功 能/可靠性测试 | Electrical Test / 电气测试 | 100% Test | Pass (See the test report) | ACC
| Solderability Test / 焊锡试验 | IPC SPEC | Pass (See the test report) | ACC
| Thermal Stress Test / 热应力试验 | IPC SPEC | Pass (See the test report) | ACC
| Ioniccontamination test/离子污染试验 | IPC SPEC | Pass (See the test report) | ACC

## Inspection Report （检验报告）

Customer code/客户代码： | D0007 | Report Rev: | M-QA-018B
Customer Part No. 客户型号: | gb-low-noise-power-probe PCB | Date/日期： | 2023/9/19
PO 订单号： | PO20230907-1 | Date Code 生产周期： | 3723
Shipment Qty 出货数量： | 10 Pcs | Sample Qty 抽样数量： | 10 Pcs

Code 编号 | Require 要求 | Plate d P/N | Tolerance 公差 | Actual 实际 | Result 结果 | Code 编号 | Require 要求 | Plate d P/N | Tolerance 公差 | Actual 实际 | Result 结果
| | | + - | | | | | | + -
1 | 0.30 | PTH | 0.075 | 0.075 | 0.320 | Acc | 16 | 2.45 | NPTH | 0.05 | 0.05 | 2.460 | Acc
2 | 0.70X1.00 | PTH | 0.075 | 0.075 | 0.72X1.00 | Acc | 17
3 | 0.70X1.50 | PTH | 0.075 | 0.075 | 0.74X1.50 | Acc | 18
4 | 0.60X100 | PTH | 0.075 | 0.075 | 0.58X100. | Acc | 19
5 | 0.60X1.50 | PTH | 0.075 | 0.075 | 0.58X1.52 | Acc | 20
6 | 0.80X1.05 | PTH | 0.075 | 0.075 | 0.82X1.06 | Acc | 21
7 | 0.80X1.30 | PTH | 0.075 | 0.075 | 0.82X1.30 | Acc | 22
8 | 0.89 | PTH | 0.075 | 0.075 | 0.920 | Acc | 23
9 | 1.00 | PTH | 0.075 | 0.075 | 1.000 | Acc | 24
10 | 1.40 | NPTH | 0.05 | 0.05 | 1.380 | Acc | 25
11 | 1.50 | NPTH | 0.05 | 0.05 | 1.520 | Acc | 26
12 | 1.70 | NPTH | 0.05 | 0.05 | 1.720 | Acc | 27
13 | 1.85 | PTH | 0.075 | 0.075 | 1.880 | Acc | 28
14 | 2.01 | PTH | 0.075 | 0.075 | 2.040 | Acc | 29
15 | 2.39 | NPTH | 0.05 | 0.05 | 2.380 | Acc | 30
编号 | Require 要求 | Tolerance 公差 | Actual 实际 | Result 结果 | Code 编号 | Require 要求 | Tolerance 公差 Code | Actual 实际 | Result 结果
| | + - | | | | | + -
1 | 124.780 | 0.13 | 0.13 | 124.73 | Acc | 21
2 | 79.780 | 0.13 | 0.13 | 79.79 | Acc | 22
3 | | | | | | 23
4 | | | | | | 24
5 | | | | | | 25
6 | | | | | | 26
7 | | | | | | 27
8 | | | | | | 28
9 | | | | | | 29
10 | | | | | | 30
11 | | | | | | 31
12 | | | | | | 32
13 | | | | | | 33
14 | | | | | | 34
15 | | | | | | 35
16 | | | | | | 36
17 | | | | | | 37
18 | | | | | | 38
19 | | | | | | 39
20 | | | | | | 40

Unit (单位) : mm

Remarks/备注:

Checked By/检查员: | Angel | Approved by/审核:

Vic

### 9.0 Hole Size Measurement 孔 径 测 量

### 10. Outline Dimensional Measurement 外 形 尺 寸 测 量

Unit (单位) : mm

Customer code/客户代码： | D0007 | Report Rev: | M-QA-018B
Customer Part No. 客户型号: | gb-low-noise-power-probe PCB | Date/日期： | 2023/9/19
Customer P/0/客户订单号: | PO20230907-1 | Date Code 生产周期： | 3723

Customer code/客户代码 | D0007 | Date Code 生产周期: | 3723
Customer Part No. 客户型号: | gb-low-noise-power-probe PCB | 测试时间 Testing time: | 2023/9/19
测试参数 Testing Parameter | 测试机别 Testing Instrument | 飞针
测试电压 Testing Tension | 300 V | 导通电阻 Permeable Resistance | 30 Ω
测试电流 Testing Current | 30 mA | 绝缘电阻 Insulation Resistance | 30 MΩ
结果 Result | 数量 Quantity | 10Pcs | 合格数量 Qualified Quantity | 10Pcs
| 开路 Open Circuit | / PCS | 线路缺陷 Circuit Matter | / PCS
| 短路 Short Circuit | / PCS | 绝缘缺陷 Insulation Matter | / PCS
| 重测 Retest | / PCS | 其它 Other | / PCS
Sam | Vic
Tested By（检查员）： | Approved By（审核)

Note1：Please baking the products 2-3 hours under 120 degrees before assembly.to eliminate moisture and perform better solderability.
Note2: we are willing to supply PCB to our customer,after get our shipment,please confirm the quality feedback within 3 months.more than 3 month's complaint from customer side,we have the right to refuse it and reject compensation. For PCBA complaint we can only accept Max.3 times of bare PCB value to afford everything consequential cost in customer side if we supplied defective PCBs to customer.

## E-TEST Report

## 测 试 报 告

1.0 Thickness of copper/孔铜厚测试(unit:um)

um

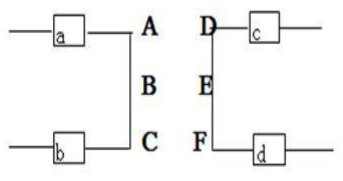
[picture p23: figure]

Request/要求 | Actual/实测 | ACC | Rej
≤ 25.4 | 12.63 | ACC
Test point/ 测试点 | Request/要求 | Actual/实际 | surface copper thickness /表铜
Point/测试点 | Request /要求 | Actual/实际
A | 20 | 25.30 | a | 1OZ | 44.40
B | | 27.80 | b | | 41.50
C | | 27.40 | c | | 46.90
D | | 25.30 | d | | 43.20
E | | 25.00 | 0.7 | 1.75
F | | 27.60 | | 35
Max | | 27.80 | | 34.28 | 46.90
Min | | 25.00 | | | 41.50
Aver | | 26.40 | | | 44.00

采样位置 Speciment Location

测试点 | 要求 Request | 实测 Actual | ACC | Rej
A | ≥ 10 | 36.20 | ACC
B | ≥ 10 | 16.50 | ACC
C | ≥ 10 | 19.73 | ACC

3.0 阻焊厚度(单位：um) Soldermask thickness (Unit:um)

2.0 Roughness/孔壁粗糙度 unit/单位 ：um

Thickness copper/铜厚 unit/单位 ：

Speciment location/采样位置

## Microsection Test Report

Customer Part No. 客户型 号 : gb-low-noise-power-probe PCB | Date 日期 : 2023/9/19
Sample Qty 样本数量 : 1PCS | Date Code 生产周期 : 3723

Lay-up | Layer 层 | Requires 要求 | Actual 实际 | Acc/Rej | Layer 层 | Requires 要求 | Actual 实际 | Acc/Rej
| L1 copper | 1OZ | 44.40 | Acc
| L1-L2 | 120.00 | 118.47 | Acc
| L2 copper | 1OZ | 33.40 | Acc
| L2-L3 | 1130.00 | 1112.58 | Acc
| L3 copper | 1OZ | 33.48 | Acc
| L3-L4 | 120.00 | 118.16 | Acc
| L4 copper | 1OZ | 43.20 | Acc
Item/项目 | Request要求 | Actual/实际 | Acc | Rej
镀层裂纹 plating crack | Not found | Not found | Acc
树脂内缩resin recession | Not found | Not found | Acc
镀层空洞 plating void | Not found | Not found | Acc
分层 delarmination | Not found | Not found | Acc
钻污 smear | Not found | Not found | Acc
铜裂缝 copper crack | Not found | Not found | Acc
起泡 blistering | Not found | Not found | Acc
连接面分离 interconnection separation Not found | | Not found | Acc
基材空洞 laminate void | Not found | Not found | Acc
灯芯 wicking | ＜0.1mm | ＜0.02mm | Acc
钉头 nail heading | Not found | Not found | Acc
■ 合格Pass | □ 不合格NG
sam | Vic

Finial result :

Prepared by/制作人： | Approved by/审核人：

5.0.Defects Inspection/缺陷检测

4.0 Copper and dielectric Thickness for multilayer board /压合叠构 unit/单位：um

样品编号 Sample NO. | 试验温度 Test temperature | 试验时间 Test time | 试验次数 Test times | 检查结果 Check result | 判定结果 Final result
1 | 255℃ | 3S | 1次 | 符合测试标准 Conformance 不符合测试标准 Non-conformance | 合格Pass 不合格NG
| | | | 符合测试标准 Conformance 不符合测试标准 Non-conformance | 合格Pass 不合格NG

□ 不合格NG

Tested By（检查员）： | Sam | Approved By（审核）： | Vic
Result(结论 )： | ■ 合格Pass

Remark(备注)：

试验依据：《IPC-J-STD-003 印制板可焊性试验》
Test Method According to《 IPC-J-STD-003 Solderability Test for Printed Boards》

An area of 3.0mm width from the trailing edge of each test specimen shall not be evaluated. Areas contacted by fixtures shall not be evaluated.A minimum of 95% of each of the surface(i.e.,each pad)being tested shall exhibit good wetting. The balance of the surface may contain only small pin holes,dewetted areas,and rough spots provided such defects are not concentrated in one area. For less critical applications,a smaller percent coverage may be determined between vendor and user.There shall be no nonwetting or exposed base metal within the evaluated area.

表面评估-接受/不接受标准
离样板边缘3.0mm以内的区域和样品夹持部位不做评估。测试样板上每个焊盘至少有95%面积上锡良好，可允许有5%面积出现轻微 针孔、锡面粗糙、上锡不良等，但是这些缺陷不能集中在同一区域；若经客户同意，可适当放宽条件，但是不能有不上锡或金属裸露等 缺陷。
Plated-Through Hole Evaluation
For finished board thickness <3.0mm,Class 1 and Class 2 Product-Solder shall fully wet the wall area of the plated-through holes,and plug holes less than 1.5mm diameter(complete filling is not necessary).Class 3 Product-The test specimen has soldered successfully if solder has rise in all plate-through holes.The solder shall have fully wetted the walls of the hole.There shall be no nonwetting or exposed base metal on any plated-through hole.

镀通孔评估
对于板厚<3.0mm的样板,1、2级标准要求其孔壁须完全润湿，直径<1.5mm的塞孔允许不完全填满锡；3级标准要求所有金属通孔中 的焊料已完全攀升，焊料完全润湿了孔壁，没有不润湿或暴露金属基材的迹象。

## Solderability Test Report

## 可 焊 性 试 验 报 告

可焊性试验的条件： a、有铅锡可焊性试验温度为：235±5℃；b、无铅锡可焊性试验温度为：255±5℃；c、其它：

Solderability Test Condition:
a、Tin/Lead Solderability testing shall be done at a solder temperature of 235±5℃；
b、Lead-Free Solderability testing shall be done at solder temperature of 255±5℃；c、Others:
Surface Evaluation-Accept/Reject Criteria
号 : | gb-low-noise-power-probe PCB | Test Date 试验日期 : | 2023/9/19 Customer Part No. 客户型
Date Code 生产周期 : | 3723 | Sample Qty 样本数量 : | 1PCS

Test Method（试验依据）：Accordance With IPC-TM-650 Or Customer Specification （IPC-TM-650标准或是客户要求）
Apparatus（设备）：Solder Pot Thermometer Flux（锡炉 温度计 助焊剂）
Specimens Pre-baking Condition（烤板条件）： | Temperature 121℃－149℃ | Time： | Hours
（温度121℃－149℃ | 小时）
Test Condition（实验条件）： | Soldering Temperature ：288±5℃, Soldering Time ：10-0/+1Sec, 3 Cycles
（288±5℃ 浸锡,时间：10-0/+1秒,3次 ） Or Others 或其它要求：

Visual Inspection（外观检查）：

1．Color Change(变色)：

3．Delamination(爆板）：

5．Measling(白斑)：

7．Solder Mask Peel Off (甩S/M)：

Microsectioning（微切片）：

1．Corner Crack(角裂)：

3．Hole-Wall Separation（孔壁分离）：

5．Delamination (爆板)：

Remark（备注）：

Disposition（判定）： | ■ 合格Pass | □ 不合格REJ
Tested By（检查员）： | Sam | Approved By（审核）： | Vic
NO | 4．Lifted Lands(焊盘浮起)： | NO
NO | 6．Resin Recession(树脂收缩)： | NO
NO | 6．Blow-Hole(吹孔)： | NO

NO

NO | 2．Hole Wall Crack(孔壁断裂)： | NO

Test Result（测试结果）

NO | 2．Wrinkles(起皱)： | NO
NO | 4．Blisters (起泡)： | NO

### Thermal Stress Test Report

### 热应力冲击试验报告

Customer Part No. 客户型号 : | gb-low-noise-power-probe PCB | Test Date 试验日期: | 2023/9/19
Date Code 生产周期 : | 3723 | Sample Qty 样板数量: | 1PCS

Customer code /客户代码： | D0007 | Customer Part No.
Date Code 生产周期 : | 3723 | 测试时间 Testing time | 2023/9/19
项目 Item | 要求 Design | 实测 Actual | 层数 Layer | 其他 Other
最大 Max | 最小 Min | 平均 Average
单端阻抗 Unitline Impedance (ohm) | 50+/-5 | 51.54 | 49.21 | 50.38 | L1
| 50+/-5 | 51.74 | 48.25 | 50.00 | L2
| 50+/-5 | 51.94 | 48.24 | 50.09 | L4
Sam | Vic

## Characteristic Impedance Test Report

## 阻抗测试报告

客户型号 : gb-low-noise-power-probe PCB

差分阻抗 Differential impedance

检查仪器 Inspection Method | Cits500 by TDR
结论 Conclusion | ■ Pass □ Fail □ Others
Tested By（检查员） | Approved By（审核）：

TEST METHOD : In accordance with QAI033
APPARATUS : Ionic contamination tester omegamenter 600SMD REQUIREMENT : Ionic contaminaton leve ≤ 1.56 ug,Nacl/sq.cm.
■ Automatic（自动） | 2020/9/2 1:12
Starting resistivity reading(起始电阻率）： | 49.60 megohms
Solution type(溶液类型）： | % is opropy 1 alcohol /
Total speciment surface area (样板总面积）： | sq . In.
Volume of solution used (溶液体积）： | mls
Ending resistivity reading (终点电阻率）： | megohms
Equivalent to (相当于）： | ug.Nacl/cm²

Test Record as follow( 记录）：

Dispositon : | ■ 合格ACC | □ 不合格REJ
TEST BY | : | Date:
Approved by : | Date:

2023/9/19

Vic | 2023/9/19

154.3

/

27.94

0.198

Angel

Test time（测试时间） : | 14:50

## Ioniccontamination test report

## 离子污染测试报告

Customer Part No. 客户型号 | gb-low-noise-power-probe PCB | Test Date 试验日期 | 2023/9/19
Date Code 周期 | 3723 | Sample Qty 样板数量 | 1PCS

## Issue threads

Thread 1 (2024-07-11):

Increaseing the offset voltage.

smarley2, 2024-07-11:
Hi, on the next release could you consider increasing the offset voltage up to 60Vdc?
I think would be necessary to change only the R5, right?
Did you had a change to evaluate the noise on the real device and using different/better opamps?

blinken, 2024-07-11:
Thanks for reaching out! Decreasing R5 to eg. 1k should work, though you'll start running in to the voltage ratings on other components. Input gain will change from -10 to -50. There may be impacts on the noise figure (but I haven't thought about it in detail), and there will be impact to the frequency response due to the higher bias voltage on C1 & friends.

I just received the first boards back for revision 1.0.1 (https://kicanvas.org/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 ) and I'll take a look at them (and this proposal) over the weekend. But there's no major reasons why it wouldn't work if you ensure the passive components are rated sufficiently well at the voltage & frequency range you need.

smarley2, 2024-07-13:
Ok, nice.
Do you have a list of changes to the 1.0.1v?
Because you mentioned some bug fix.
Have you tried in the simulation a different opamp?
Have you found the reason of the spike on the simulation? Did you tried ltspice instead of Tina?

Best regards

blinken, 2024-08-01:
I just completed the characterisation today for v1.0.1, see https://github.com/blinken/power-rail-probe?tab=readme-ov-file#v101-3

- The frequency response is a bit better, but not as good as I'd like it (the goal is <1dB variation between 100kHz and 500MHz, and we're close but not quite there). I wonder if the parasitic inductance of RV1 (the potentiometer) is causing the issue, and may need compensation.
- LEDs that indicate whether the device is above or below range are now added to the front panel
- An indicator LED that shows when the USB power supply is connected is added to the rear panel
- RV1 is specified as a 5-turn potentiometer for easier adjustment.
- Layout is improved to isolate the AC path from the DC path a little more.

I also tested changing R5 to 1k, and it does work well to increase the range of measurable voltages - I was able to measure my 30V power supply output quite comfortably @ 10mV range on the oscilloscope. However, with 50V AC-pass capacitors the I believe frequency response is quite poor by ~30V DC bias (but I lack an accurate bias tee to test with).

I think if we switch to 100V-rated components for the AC pass capcacitors, then it should be ok to change R5 to ~3.3k and get the extra range from the device.

blinken, 2024-08-01:
Just on opamps, the OPA322 was selected based on the following requirements

- Rail to rail output
- Low noise
- Output drive capability into 50 ohms at 2V

The last requirement in particular limits the selection quite a bit, but suggestions for better parts compared with the OPA322 are welcome.

smarley2, 2024-08-02:
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

On Kicad Sch you have two OPA332.
But you are using the LMP7731 on the input and the OPA332 just to invert, right?
Because if look TI you can find that LMP7731 is the less noise they have with rail to rail input.

Take a look on OPA323 to replace the OPA332, seems to be a better device.

smarley2, 2024-08-02:
Also, another point.
Did you try to do a different approach like:
Connect the AC cap directly to the output.
Connect the OPA with 50R to the output with G=2.
So you could have 1:1 probe, but I'm not sure how about the noise when you amplify with OPA.
Could you try to simulate it and see the impact?

blinken, 2024-08-02:
Take a look at this article
https://circuitcellar.com/research-design-hub/projects/building-a-power-rail-probe/
which is a similar design, and covers your questions/the design decisions
in detail (much better than I can here!)

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

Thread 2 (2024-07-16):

Balancing circuit

smarley2, 2024-07-16:
Hi, are you thinking in a balancing circuit for the cells while charging?
Seems that actual charging IC does not do it.

blinken, 2024-08-01:
Thanks for the comment!

That's correct, the charging IC just charges the cells in series. I don't feel cell balancing is necessary at this stage - my expectation is that the current draw from the cells is so small that it's unlikely they'll become unbalanced in a short space of time.

Adding a balanced charger would be complex with the current switched-ground design, bearing in mind it needs to be out of circuit during operation to avoid any introduced noise.

Potentially, once every couple of years, the user might need to remove the cells and charge them individually, but that seems like an ok compromise.

Closed 2024-08-01.

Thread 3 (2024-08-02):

Results from V1.01

smarley2, 2024-08-02:
Hi, can we talk about the results you got?

Did you try different values of L in the output of OPA?
Seems that is highly relevant for the deep you have when change from the Opamp to the capacitor.

What's the limitation factor you think you have to not achieve higher frequencies?
The parasitic inductance would reduce your bandwidht, but your trace on the layout seems to be very short on the AC path.
You think is due to the capacitor parasitic? Did you try different PN of capacitors?

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

blinken, 2024-08-02:
> Did you try different values of L in the output of OPA?
> Seems that is highly relevant for the deep you have when change from the Opamp to the capacitor.

Yes, I spent a couple of weeks on this t the beginning of the year. The optimal values are the ones chosen - take a look at https://hachyderm.io/@blinken/111671085003017347 and https://hachyderm.io/@blinken/112859345117485764 (v1.0.1) for a discussion of this. Make sure you're looking at the correct schematic for v1.0.1 (https://kicanvas.org/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)

I thought as recently as a couple of weeks ago that the dip in S12 at ~750kHz was down to opamp compensation, but I'm increasingly convinced it's due to the inductance of RV1 (the potentiometer). I've tried replace this in the past, with no change, but I think I'd like to look in more detail.

Note that removing C2 improves the frequency response @ 750kHz, so I'm removing it from shipping boards going forward & will update the schematic shortly.

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

> What's the limitation factor you think you have to not achieve higher frequencies?
> The parasitic inductance would reduce your bandwidht, but your trace on the layout seems to be very short on the AC path.
> You think is due to the capacitor parasitic? Did you try different PN of capacitors?

Yes :)

From simulation I believe the limitation for higher frequency response is the BNC connectors. I'd like to try a dual footprint with SMA on the next board revision to see if it helps.

I get the same frequency response (falloff @ ~500MHz) in simulation if I insert 10p of capacitance here:

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

It might also be something like the interaction between R2 & the connector capacitance forming a low-pass filter, but R2 is needed to damp down the notch filter formed by C1 and L1.

I've added the simulation file under doc/v1.0.1/v1.0.1.TSC if you would like to have a look.

smarley2, 2024-08-02:
On your measurement, are you considering the cable also, or you calibrated the VNA and connected directly to the device?
Because if you look a low noise cable like LMR195 it will give to you 83.3pF/m (https://www.koax24.de/storage/datasheet/de/050123_Datenblatt_-_LMR-195.pdf)

And how about removing the output resistor that you think is making the filter?
Try something like this and check how is the noise and the response:
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

blinken, 2024-08-02:
Sorry to say that I don't have time to work on the probe this week, but please feel free to try and report back on how it looks in simulation! I'd be interested to see what you find.

We use a calibrated HP 8753ES in our lab with these cables: https://docs.rs-online.com/d8ff/0900766b81570f7c.pdf. The VNA calibration is done with a calibrated/traceable cal kit at the tip of the cable.

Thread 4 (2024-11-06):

some questions about your low cost power rail project

GaryWang1979, 2024-11-06:
Hi Blinken,

Thanks for your share your good idea. I have the below questing and need your help:
1. form your schematci: V2_out=10*VRV1+Vj1  ( vj1 is the probe input voltage) . why do you the the gain is 1:1.25?
2. OPA322 max output voltage=2.5V. if we hope to testing a 12V (for example) DC, how it will show 12 V in the scope screen?( for scope port, the general max input is 5V ). Do we will set scope atten to show 12V voltage. if we set the scope atten. what the value will be set for the different testing voltage(if we adjust VR1, what the atten we will set in the scope?

thanks

Gary

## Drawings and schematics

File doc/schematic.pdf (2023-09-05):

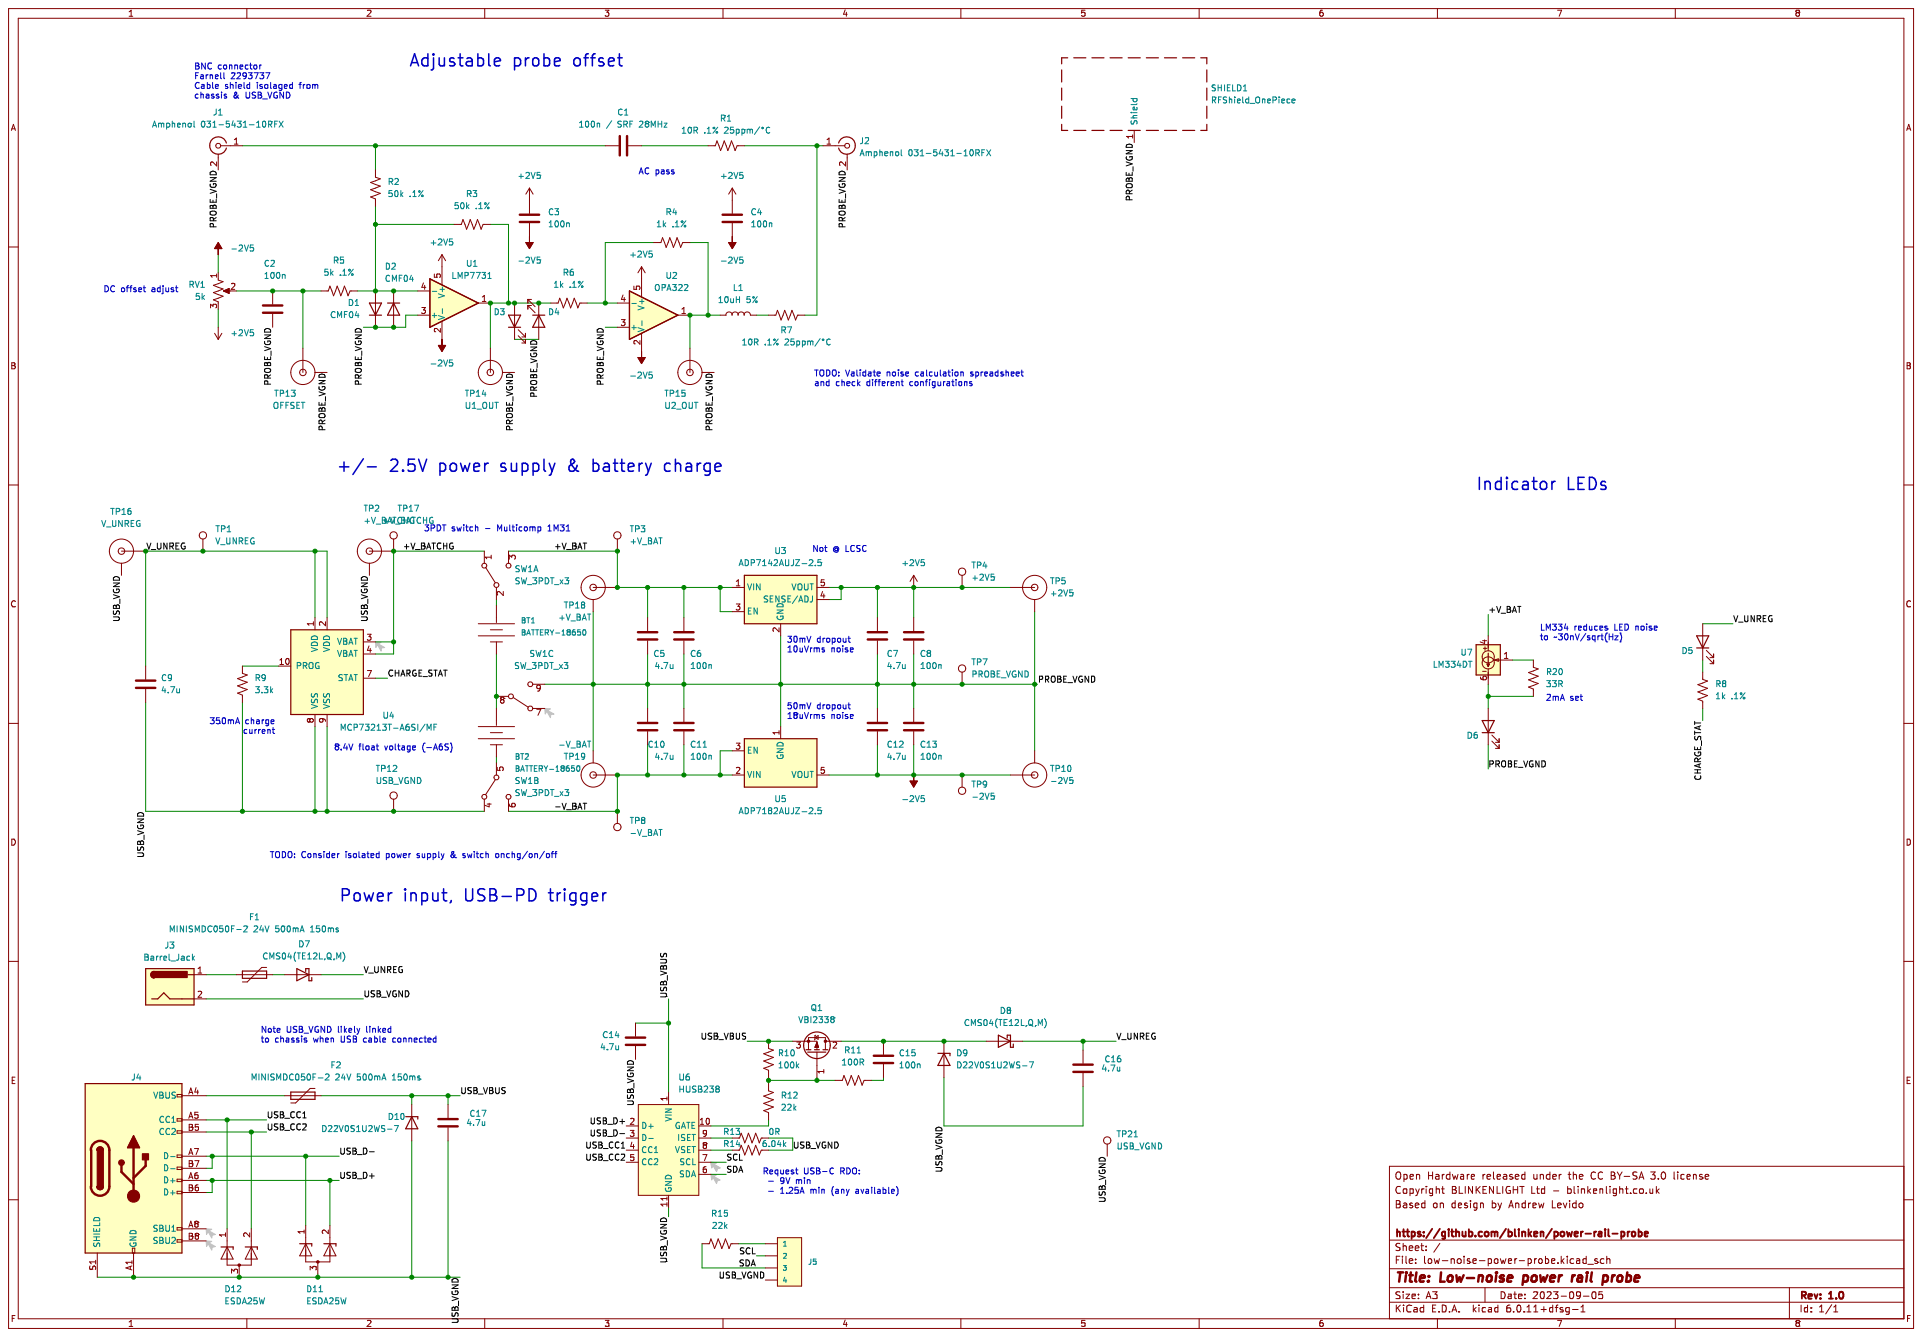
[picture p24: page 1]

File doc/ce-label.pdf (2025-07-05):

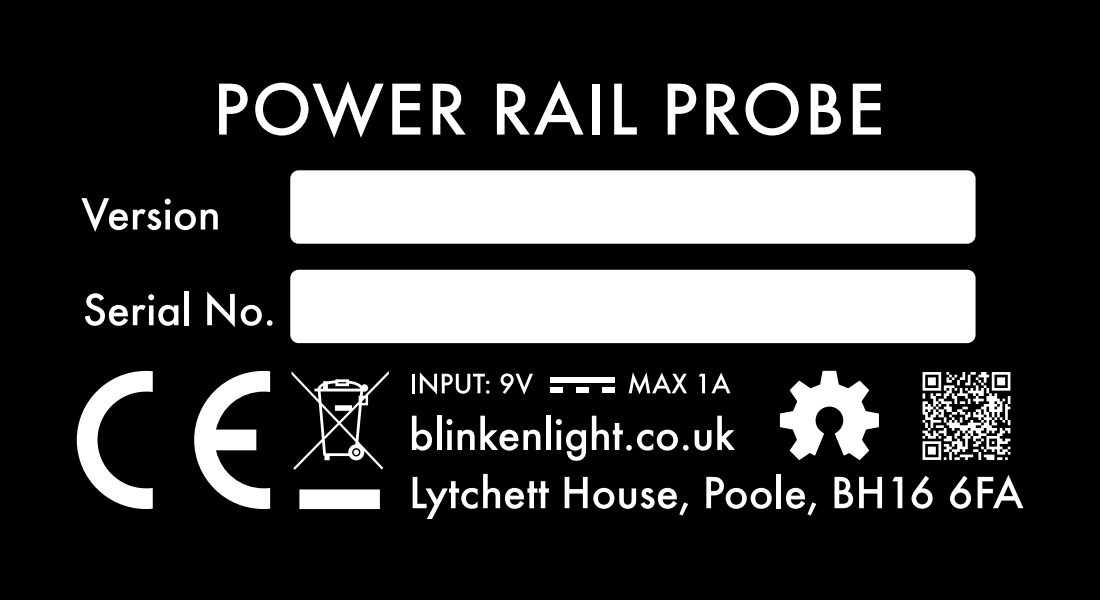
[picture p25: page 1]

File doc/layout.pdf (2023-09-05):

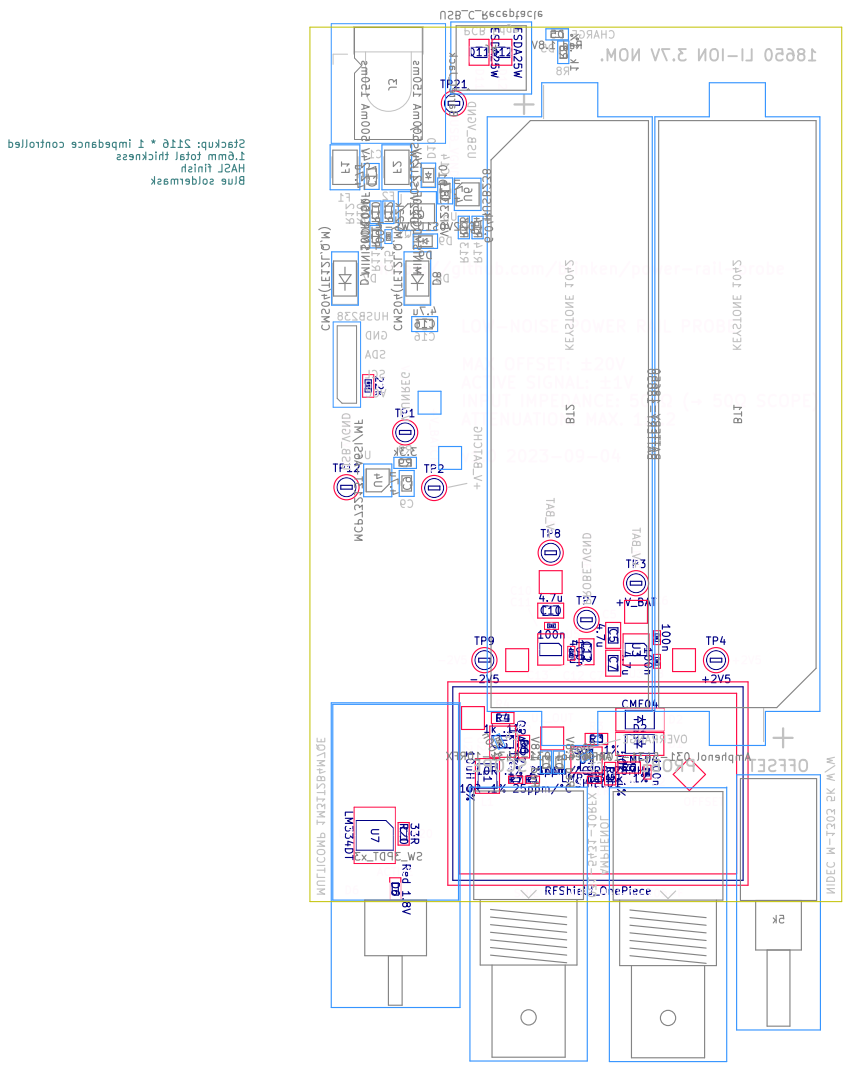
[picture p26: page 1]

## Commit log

2023-07-16 Initial commit - schematic mostly there, USB-PD still needs more work.
    [low-noise-power-probe.kicad_pcb, low-noise-power-probe.kicad_sch]
2023-07-16 Add case images
2023-07-18 Complete the USB-PD design, select parts for most main components.
    [low-noise-power-probe.kicad_sch]
2023-07-18 Add comment re STUSB4500
    [low-noise-power-probe.kicad_sch]
2023-07-18 Add KiCanvas link for schematic
2023-07-30 add noise analysis - comparison of two options for the inverting opamp, OPA322 (selected) and TLV9061
    [noise-analysis.ods, noise-analysis.xlsx]
2023-07-30 schematic v1.0 for review
    First pass at schematic for review. The original design called for two
    opamps - a summing LMP7731 and an inverting TLV2460. Unfortunately the
    TLV2460 has been discontinued, so I took the opportunity to update the
    design for the OPA322. This appears to offer better noise
    characteristics while retaining rail-to-rail swing @ >20mA output,
    required to drive 1.0V into 50ohms.
    Major component placement is complete on the PCB & front panel sketches
    are done.
    [low-noise-power-probe.kicad_pcb, low-noise-power-probe.kicad_sch]
2023-07-31 add PDF and PNG layout and schematic
2023-09-05 v1.0 gerbers as-manufactured
    Schematic and PCB verification completed and corrections made. Add BOM,
    excluding THT components, and CPL file for automated assembly.
    Add script that adds 5mm edge rails to a "panel" for assembly, and add
    the panel.
    [low-noise-power-probe-bom-pcba.csv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]
2023-09-05 update readme for version 1.0
    [low-noise-power-probe.kicad_pcb, low-noise-power-probe.kicad_sch]
2023-09-05 add part numbers to schematic in more places
    [low-noise-power-probe.kicad_sch]
2023-10-10 production files for test run
    [front-panel-marked-14.dxf, front-panel.3mf, front-panel.dxf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]
2023-12-30 remove old noise analysis spreadsheets
    [noise-analysis.ods, noise-analysis.xlsx]
2023-12-30 clean up the README
    Make the language clearer. Mention that blank PCBs and enclosures are
    available.
2024-01-01 revisions for v1.0.1
    Minor revisions to fix bugs, reduce unique components and improve
    manufacturability.
    * Reduce component count by consolidating resistor values
    * Drop protection diodes and replace them with 625ohm resistors to
    reduce the potentiometer swing
    * Add an indicator LED that shows when the USB-C bus is > approx. 6V
    (ie. at least 9V has likely been negotiated)
    * Add opamp decoupling caps between +2.5 and -2.5 and GND. Make the existing
    decoupling +2.5/-2.5 DNP. Add 4.7 bulk decoupling.
    * Flip the orientation of the power switch so it matches the front
    panel
    * Add additional capacitors in parallel for the AC path, to improve the
    frequency response
    * Add DNP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
    [low-noise-power-probe.kicad_sch]
2024-01-01 v1.0.1, further simplification
    * Swap the standalone ESD diodes for the ESDA25W package already in use
    elsewhere
    * Swap the CMS04 schottky diodes for cheaper 1N5819WS, as they're only
    used for reverse polarity.
    [low-noise-power-probe.kicad_sch]
2024-06-24 v1.0.1, as manufactured
    A number of small layout changes, including a switch to a dual battery
    holder.
    Adjust the BOM to select parts that are in stock and more commonly
    Mark the switch orientation clearly on silkscreen so we don't make the
    same mistake again and reverse ON/CHG.
    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
    [low-noise-power-probe-panel-B_Cu.gbr, low-noise-power-probe-panel-B_Mask.gbr, low-noise-power-probe-panel-B_Paste.gbr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]
2024-09-12 minor reference and component value clarifications
    [low-noise-power-probe.kicad_sch]
2024-09-12 remove C2 from BOM and mark DNP to improve frequency response
    [low-noise-power-probe.kicad_sch, low-noise-power-probe_bom_jlc.csv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]
2025-07-05 commit unchecked changes for 1.0.1
    [low-noise-power-probe-bom-pcba.xlsx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]
2025-07-07 v2.0, almost ready for DRC
    [low-noise-power-probe.kicad_pcb, low-noise-power-probe.kicad_sch]
2025-07-08 add panel and gerbers for v2.0
    [low-noise-power-probe-panel-B_Cu.gbr, low-noise-power-probe-panel-B_Mask.gbr, low-noise-power-probe-panel-B_Paste.gbr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]
2025-08-22 v2.0, as manufactured and tested
    Add v2.0. The schematic contains some additional revisions beyond the
    BOM to improve frequency response.
    [low-noise-power-probe-panel-B_Cu.gbr, low-noise-power-probe-panel-B_Mask.gbr, low-noise-power-probe-panel-B_Paste.gbr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]
2026-01-13 v2.1, fix battery protection and minor improvements
    - Fix the battery protection properly - use individual protection for
    each cell using the HY2213 for balancing and the DW01A for protection.
    While not perfect, this should provide reasonable protection while
    allowing us to take the battery centre tap safely.
    - Amend board notes to include the latest JLCPCB stackup/material spec
    - Add an impedence control spreadsheet for JLC
    - Tweaks to component selection for in stock/precision
    - Shift LEDs back away from board edge to aid assembly (light pipes
    were hitting them).
